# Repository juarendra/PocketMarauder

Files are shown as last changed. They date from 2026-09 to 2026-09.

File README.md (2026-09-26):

# PocketMarauder

Perangkat pentest saku: **ESP32-WROOM-32D + OLED 128x64 (SSD1306) + 4 tombol**, berjalan di firmware fork [ESP32Marauder](https://github.com/Spacehuhn/ESP32Marauder) dengan 4 fitur pentest tambahan yang di-build khusus untuk target `POCKET_MARAUDER`.

```
[ OLED 128x64 ]   [ ESP32-WROOM-32D ]
  I2C (IO21/22)     [ A ] [ B ] [ C ] [ D ]   (IO35/32/33/25)
                    Bat: LiPo via TP4056 (IO34)   LED aktif: IO19
```

> **Gambar hardware**: [`docs/images/hardware-placeholder.png`](docs/images/hardware-placeholder.png) — masih placeholder; foto/diagram asli menyusul.

## Fitur

### Firmware bawaan ESP32Marauder (v1.17.0)
- **WiFi** — sniffers (beacon/probe/deauth/EAPOL), scanners (channel analyzer, PineScan, Fox Hunt), attacks (deauth, beacon spam, Karma, Evil Portal, SAE commit, dst.), packet monitor.
- **Bluetooth** — sniffers (BLE scan, FindMy/Airtag, CC skimmer), attacks (Sour Apple, BLE spam, Spoof Airtag).
- **OLED natif** — menu + status bar + persentase baterai, tanpa TFT.
- **Baterai** — ADC IO34 (divider 5.02×), ditampilkan % di status bar.
- **LED aktivitas** — hijau di IO19, menyala saat scan/attack aktif.

### Fitur tambahan (khusus PocketMarauder)
| Fitur | Menu | Fungsi |
|---|---|---|
| **WPS Scan** | WiFi → Sniffers | Pasif: deteksi AP yang mengiklankan WPS, flag `PIN-PRONE` / `LOCKED` |
| **Probe Spam** | WiFi → Attacks | Flood probe request dengan SSID acak |
| **Roam Bait** | WiFi → Attacks | Beacon palsu dengan IE 802.11r (MD) + 802.11k (RM caps) |
| **GATT Explore** | BT → Attacks | Koneksi BLE, enumerasi services/characteristics/values |

Detail penggunaan per fitur: [`docs/USER_MANUAL.md`](docs/USER_MANUAL.md).

## Hardware

| Komponen | Detail |
|---|---|
| MCU | ESP32-WROOM-32D (2.4 GHz WiFi + BLE) |
| Tampilan | SSD1306 OLED 128x64 mono, I2C addr `0x3C` (SDA=IO21, SCL=IO22) |
| Tombol | A=Up (IO35), B=Left/Back (IO32), C=Center/Select (IO33), D=Down (IO25) — active-low, pull-up 10k |
| Baterai | LiPo via charger TP4056 + proteksi; tegangan dibaca IO34 (ADC1_CH6, divider 10k/40.2k) |
| LED | Hijau IO19 (active-low), indikasi aktivitas scan |
| Antena | U.FL — gunakan antena tersambung untuk hasil scan maksimal |

PCB/EAGLE source: [`PCB/EAGLE/`](PCB/EAGLE/).

## Build & Flash

Prasyarat: [PlatformIO](https://platformio.org) CLI + Python 3.

```bash
cd firmware
python -m platformio run -e pocket_marauder        # build (~60 detik)
python -m platformio run -e pocket_marauder -t upload   # flash (butuh USB flasher)
python -m platformio run -e pocket_marauder -t monitor  # serial monitor
```

Build terakhir: **GREEN** — Flash 81.7% (1605679/1966080), RAM 24.9% (81724/327680).

Output: `firmware.bin` (app) + `firmware.factory.bin` (gabungan bootloader + partisi + app).

## Struktur Repo

```
firmware/            firmware (fork ESP32Marauder, target POCKET_MARAUDER)
  esp32_marauder/    source utama
  tools/             build helpers PlatformIO
  installer/         build pipeline installer
PCB/EAGLE/           source PCB (schematic)
docs/
  USER_MANUAL.md     manual pengguna (lengkap)
  images/            simulasi tampilan OLED + placeholder hardware
  plans/             rencana kerja internal
CHANGELOG.md         log perubahan
```

## Lisensi

[GNU GPL v3](LICENSE). Fork dari ESP32Marauder (upstream juga GPLv3).

## Disclaimer

Alat ini untuk **pengujian keamanan yang sah** (lab sendiri, jaringan sendiri, atau dengan izin tertulis pemilik jaringan). Penggunaan di jaringan yang tidak kamu miliki tanpa izin adalah **ilegal** di hampir semua yurisdiksi. Pengguna bertanggung jawab penuh atas perbuatannya.

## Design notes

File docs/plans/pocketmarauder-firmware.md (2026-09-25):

# PocketMarauder — Review & Plan

Updated: 2026-09-25
Status: PLAN — belum eksekusi, nunggu approval

## 1. Review Hardware (dari EAGLE sch + BOM + gerber)

Board: **espmarauder v2 / "PocketMarauder"** — SlimeVR by Positron Elektronik.
Sumber: `PCB/EAGLE/espmarauder.sch` (EAGLE 9.6.2), BOM `CAMOutputs/Assembly/espmarauder.txt`,
gerber `espmarauder_production_2026-03-05.zip`.

### Fakta terverifikasi
- **MCU**: ESP32-WROOM-32D (single unit; board produksi = 2 unit identik di-panel, konfirmasi user).
- **USB-UART**: FT231XS-R (auto-program via DTR/RTS Q1/Q2).
- **Power**: TP4056 charger + DW01A/FS8205A Li-ion protection + M3406-ADJ buck 3.3V + SI2301 P-MOSFET load switch. JST-PH2 battery + slide switch BATT_SW.
- **Display**: **OLED 128x64 I2C SSD1306** (`DISPLAY-OLED-128X64-I2C`, U$1).
  - SDA = **IO21**, SCL = **IO22**.
- **Buttons** (4x tactile 4x4, active-low, pull-up eksternal 10k):
  | Fungsi fisik | Net | GPIO | Pull-up |
  |---|---|---|---|
  | BTN A | D35 | **IO35** | R6 10k |
  | BTN B | D32 | **IO32** | R11 10k |
  | BTN C | D33 | **IO33** | R18 10k |
  | BTN D | D25 | **IO25** | R19 10k |
  - Catatan: net `BUTTON1` ada di **IO18** tapi tanpa komponen tombol → sisa template, abaikan.
  - IO35 = input-only (OK, pakai pull-up eksternal, tak bisa internal).
- **LED user**: LED = **IO19** (R9 330), LED2 = **IO26** (R20 330). Plus CHRG/STBY/RX/TX status LED (hardware, bukan GPIO).
- **microSD**: **TIDAK ADA** konektor di BOM. Net `SD_HOST_*` (IO2/4/12/13/14/15) = sisa template → matikan (konfirmasi user).
- **UART2** IO16/IO17 (RX_DWM/TX_DWM): bekas project lain → abaikan (konfirmasi user).
- **Board**: 2-layer, 80.0 x 48.5 mm, tebal 1.57mm. Gerber siap fab (EAGLE CAM, 13 file + drill).

## 2. Review Firmware (upstream justcallmekoko/ESP32Marauder v1.17.0)

### BLOCKER kritis — display incompatible
Upstream Marauder **hanya support TFT warna via TFT_eSPI** (ILI9341/ST7735/ST7789/CYD dst).
**Tidak ada driver OLED SSD1306 / monochrome sama sekali** di seluruh codebase
(cek: 0 match `SSD1306|SH1106|U8g2|Adafruit_GFX`).

`Display` class terikat erat ke API TFT_eSPI:
- `tft.drawString/setFreeFont/setTextColor`, `TFT_eSPI_Button`, warna 16-bit RGB565.
- Layout menu diasumsikan min ~135x240 px berwarna. OLED cuma 128x64 mono.

→ **Remap GPIO saja TIDAK cukup.** Board ini butuh backend display baru.

### Yang cocok tanpa modif besar
- WiFi/BT attack core (WiFiScan, EvilPortal, CommandLine) hardware-agnostik.
- `HAS_SCREEN` bisa dimatikan → firmware jalan **headless** (kontrol via serial CLI 115200).
- Build target `GENERIC_ESP32` sudah ada (screen off, button off) sebagai basis.

## 3. Arsitektur Display (KEPUTUSAN: Opsi B)
| Opsi | Effort | Hasil | Risiko |
|---|---|---|---|
| **A. Headless/CLI** | Kecil | Semua fitur attack via serial; OLED tak dipakai / status ringkas manual | Tak ada menu di device — kurang "produk" |
| **B. OLED backend baru** | Besar | Menu native di OLED 128x64 + 4 tombol | Nulis ulang layer Display (drawString, button, scroll) untuk SSD1306; port paling berat |
| **C. Fork komunitas OLED** | Sedang | Pakai fork Marauder yg sudah OLED (mis. varian 0.96") lalu remap | Perlu cari fork yg maintained & sinkron fitur; lisensi/quality bervariasi |

### KEPUTUSAN USER (2026-09-25)
- **Opsi B dipilih** — OLED backend baru (SSD1306 128x64 + 4 tombol nav).
- **Branding**: nama produk = **PocketMarauder**.
- **Boot logo**: foto French Bulldog (`local://image-c9ef49c3d688ab6a.png`, 433x577 PNG).
  → konversi ke bitmap 1-bit 128x64 (XBM), threshold/dither, di Fase 2.
- **Fitur ekstra**: user minta saran (lihat §3b).

## 3b. Saran Fitur (di luar Marauder standar)

Konteks board: OLED 128x64 mono, 4 tombol, battery Li-ion + TP4056, tanpa SD/GPS.
Semua yg butuh SD/GPS di upstream otomatis di-disable.

Prioritas layak (murah, cocok hardware ini):
1. **Battery indicator di status bar** — baca VBAT via ADC divider bila ada net battery-sense; kalau tak ada tap ADC, tampilkan status charging dari pin TP4056 CHRG/STBY (bila terhubung GPIO). Cek dulu di sch apakah ada.
2. **Nav 4-tombol yang enak** — mapping Up/Down/Select/Back (bukan 5-arah), karena cuma 4 tombol. Long-press = Back global.
3. **Boot logo + versi + nama** — splash PocketMarauder 2 detik.
4. **Sleep/backlight-off timeout** — OLED aging + hemat baterai; wake on button.

Opsional (nice-to-have):
5. Menu "Favorites" — shortcut ke 2-3 scan yg paling sering (deauth detector, beacon spam, packet monitor) biar cepat di layar kecil.
6. Indikator RAM/heap ringkas di status bar (Marauder rentan OOM).

Dihindari (tak cocok / tak ada hardware):
- Wardriving/GPS log (tak ada GPS + tak ada SD buat simpan).
- PCAP ke SD (tak ada SD) — hanya live serial dump.
### Fase 1 — Board config
- [ ] Tambah target `POCKET_MARAUDER` di `firmware/esp32_marauder/configs.h`:
  - Buttons: L/C/U/D/R → IO35/IO32/IO33/IO25 (+ mapping ke navigasi menu).
  - `HAS_BUTTONS`, `HAS_BT`, matikan `HAS_SD`/`HAS_GPS`.
  - I2C: SDA=21, SCL=22.
- [ ] Boot splash + `HARDWARE_NAME "PocketMarauder"` (branding).
- Bukti: compile config-only, cek makro resolve.

### Fase 2 — Display (sesuai opsi terpilih A/B/C)
- A: `HAS_SCREEN` off, verifikasi CLI. Bukti: serial log scan WiFi.
- B: implement `DisplayOLED` (SSD1306 via Adafruit_SSD1306/U8g2), adaptor menu. Bukti: foto OLED render menu.

### Fase 3 — Build & flash
- [ ] Build via arduino-cli (toolchain terdeteksi: `arduino-cli` ada; PlatformIO belum).
- [ ] Flash 1 unit, smoke test: boot → menu/CLI → 1 scan WiFi sukses.
- [ ] Dokumentasi prosedur flash produksi (2 unit per panel).

### Fase 4 — Cleanup
- [ ] Hapus `_tmp_marauder`, file bekas, update CHANGELOG.

## 5. Toolchain terdeteksi
- `arduino-cli` ✓ (`C:\Program Files\Arduino CLI`)
- `git`, `python3` ✓
- PlatformIO ✗ (upstream punya `platformio.ini` tapi cuma buat env `native` test; build device pakai Arduino IDE/CLI).

## 6. Keputusan yang ditunggu dari user
1. **Opsi display A / B / C?** (paling menentukan scope).
2. Branding: nama produk final, boot logo custom? (punya aset sendiri?).
3. Fitur firmware di luar Marauder standar yang mau ditambah? (blm ada, konfirmasi).

## Don't repeat
- Upstream TIDAK punya OLED driver — jangan asumsikan remap GPIO cukup untuk display.
- Board TANPA microSD & GPS meski net template ada.

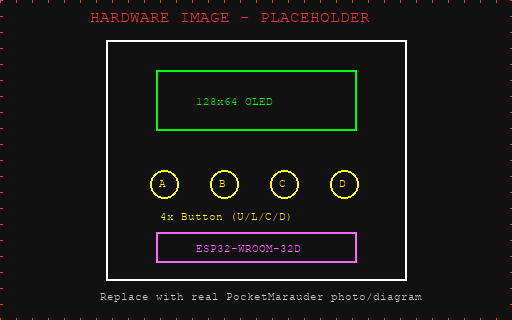
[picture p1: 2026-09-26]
docs/images/hardware-placeholder.png

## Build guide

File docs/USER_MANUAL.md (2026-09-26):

# PocketMarauder — Manual Pengguna

Manual ini menjelaskan cara menggunakan perangkat PocketMarauder dari awal: menyalakan, menavigasi menu, memakai semua fitur, sampai membaca output di serial monitor. Gambar-gambar di bawah adalah **simulasi tampilan OLED** (piksel asli perangkat adalah 128x64 mono; simulasi di-skalakan 4× agar terbaca).

---

## 1. Sekilas Perangkat

PocketMarauder adalah perangkat pentest saku berbasis ESP32 dengan:

- **OLED 128x64** monokrom — semua tampilan menu & hasil di sini.
- **4 tombol fisik** — navigasi & eksekusi.
- **WiFi 2.4 GHz** (ch 1-14) + **Bluetooth LE** (BLE 4.2/5.0).
- **Baterai LiPo** terintegrasi + **LED hijau** indikator aktivitas.

> **Gambar hardware**: [`images/hardware-placeholder.png`](images/hardware-placeholder.png)
> (masih placeholder — foto/diagram perangkat asli menyusul di folder yang sama; manual ini akan menunjuk ke file `hardware.png` begitu tersedia.)

## 2. Tombol & Navigasi

Semua tombol active-low, dengan pull-up.

| Tombol | Posisi GPIO | Fungsi |
|---|---|---|
| **A** (atas) | IO35 | Naik satu item menu |
| **B** (kiri) | IO32 | **Back** — kembali ke menu sebelumnya; menghentikan scan/attack yang berjalan |
| **C** (tengah) | IO33 | **Select/Enter** — membuka item yang disorot / memulai scan |
| **D** (bawah) | IO25 | Turun satu item menu |

Aturan navigasi:

1. Item yang disorot di-highlight (baris putih terbalik, awalan `>`).
2. Menu ber-scroll jika item melebihi satu layar.
3. Tekan **B** kapan pun untuk berhenti & kembali.
4. Setelah scan/attack selesai (ditutup tombol B), perangkat kembali ke menu utama.

## 3. Daya, Baterai, LED

### Menyalakan / Mematikan
Perangkat menyala saat diberi daya (baterai terpasang + saklar on, atau via USB charger TP4056). Tidak ada tombol power terpisah — matikan dengan memutus daya/saklar.

### Membaca Persentase Baterai
Status bar di baris paling atas OLED selalu menampilkan persentase baterai di sisi kanan (contoh: `84%`):

```
PocketMarauder                    84%
──────────────────────────────────
```

- Persentase dihitung dari tegangan baterai via divider (IO34), di-refresh tiap 3 detik.
- **Hijau** (dalam serial log) / tampilan normal: > 20%. Di bawah 20% persentase akan terlihat merah di log serial dan sebaiknya segera diisi ulang.
- Mengisi ulang: colokkan ke pengisi LiPo (port TP4056) — perangkat boleh tetap menyala.

### LED Hijau (IO19)
- **Menyala** = perangkat sedang melakukan WiFi scan/attack.
- **Padam** = idle di menu.
LED berguna untuk tahu secara sekilas (tanpa melihat layar) apakah ada operasi berjalan.

## 4. Urutan Boot

1. **Splash** — logo + "PocketMarauder" + versi, ~1 detik.
2. Inisialisasi OLED, WiFi radio, BLE.
3. Menu utama muncul; status bar mulai menampilkan persentase baterai.

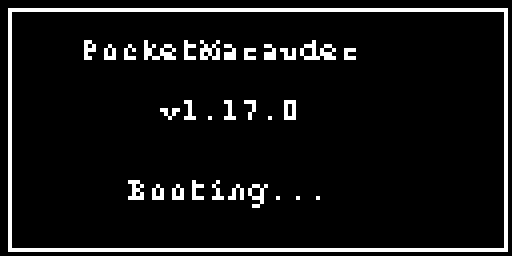
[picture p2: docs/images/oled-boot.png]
Boot


## 5. Struktur Menu

```
Main Menu
├── Recon            → (aplikasi umum)
├── WiFi
│   ├── Sniffers     → Probe / Beacon / Deauth / EAPOL / Packet Monitor /
│   │                  Channel Analyzer / SA Commit / ★ WPS Scan
│   ├── Scanners     → Channel Analyzer & Summary, Fox Hunt, MAC Monitor
│   ├── Attacks      → Beacon List / Beacon Spam / Evil Portal / Deauth /
│   │                  ★ Probe Spam / ★ Roam Bait / Karma / Bad Msg / dst.
│   └── General Apps → Evil Portal, dll.
├── Bluetooth
│   ├── Sniffers     → Bluetooth Sniff, FindMy, CC Skimmers, Fox Hunt
│   └── Attacks      → Sour Apple, Apple Juice, Swiftpair Spam, BLE Spam,
│                      Spoof Airtag, ★ GATT Explore
├── Device           → info perangkat (versi, MAC, memory, baterai)
└── Reboot           → restart perangkat
```

`★` = fitur tambahan khusus PocketMarauder.

### 5.1 Main Menu

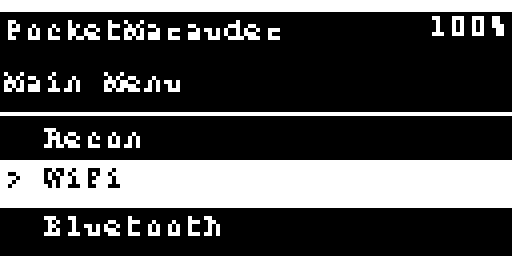
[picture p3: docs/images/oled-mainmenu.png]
Main Menu


Sorot `WiFi` (tombol A/D), tekan **C**.

### 5.2 Menu WiFi

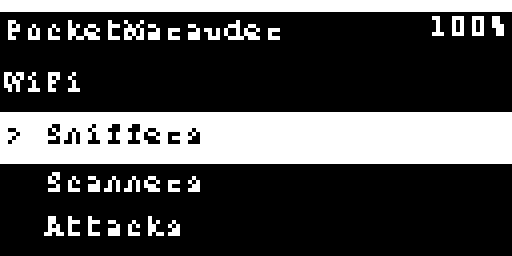
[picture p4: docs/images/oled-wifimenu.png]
Menu WiFi


### 5.3 Submenu WiFi → Sniffers

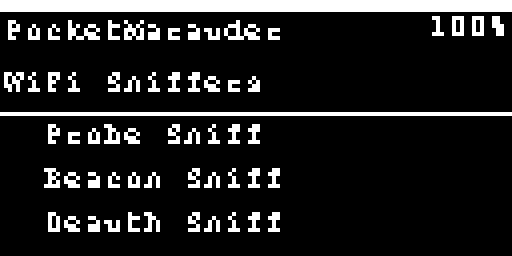
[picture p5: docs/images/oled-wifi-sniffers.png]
WiFi Sniffers


### 5.4 Submenu WiFi → Attacks

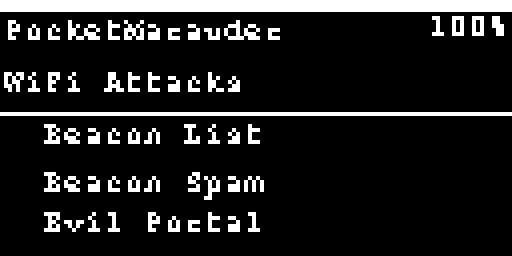
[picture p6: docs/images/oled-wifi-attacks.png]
WiFi Attacks


### 5.5 Submenu BT → Attacks

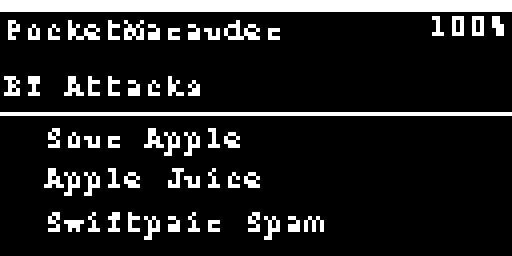
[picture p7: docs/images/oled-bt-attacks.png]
BT Attacks


## 6. Fitur Bawaan (ringkasan)

Fitur-fitur berikut berasal dari firmware ESP32Marauder upstream dan bekerja standar. Berikut ringkasan singkat; untuk detail penuh, konsultasikan dokumentasi upstream.

### 6.1 WiFi Sniffers
| Item | Yang dilakukan |
|---|---|
| **Probe Sniff** | Menangkap probe request dari client WiFi (SSID yang dicari client) |
| **Beacon Sniff** | Menangkap beacon frame — daftar AP di sekitar (SSID, MAC, channel, RSSI, encryption) |
| **Deauth Sniff** | Menangkap deauthentication frame |
| **EAPOL** | Menangkap frame autentikasi WPA handshake |
| **Packet Monitor** | Visualisasi throughput/frame rate secara real-time |
| **Channel Analyzer** | Grafik okupansi per channel |
| **SAE Commit** | Menangkap WPA3 SAE commit |

Hasil muncul di layar (baris-baris AP) dan di serial monitor (lebih lengkap).

### 6.2 WiFi Scanners & Attacks (bawaan)
- **Channel Summary / Analyzer** — okupansi channel 1-14.
- **Fox Hunt** — lacu AP/STA spesifik.
- **MAC Monitor** — deteksi perangkat yang "mengikuti" (mac monitor).
- **Beacon List / Beacon Spam** — broadcast beacon SSID dari list.
- **Evil Portal** — captive portal + portal phishing framework.
- **Deauth** — kirim deauth (broadcast atau targeted).
- **Karma** — probe-based SSID replay.
- **Bad Msg / Assoc Sleep / SAE Commit Flood / Channel Switch / Quiet Time** — varian attack lain.

### 6.3 Bluetooth
- **Bluetooth Sniff** — scan BLE umum (nama, MAC, RSSI) → juga mengisi daftar device yang dipakai fitur GATT Explore (lihat §7.3).
- **FindMy Sniff/Monitor** — deteksi AirTag & tracker FindMy.
- **CC Skimmers** — deteksi skimmer kartu kredit berbasis BLE (NFC/CC).
- **Sour Apple / Apple Juice** — Apple BLE spam.
- **Swiftpair Spam / Samsung / Google / Flipper BLE Spam / BLE Spam All** — flood BLE advertisement.
- **Spoof Airtag** — simulasi AirTag.

## 7. Fitur Tambahan PocketMarauder (Detail)

Keempat fitur di bawah adalah penambahaan di firmware ini. Output detail keempatnya **terutama tampil di serial monitor** — layar OLED menampilkan status berjalan; hasil lengkap (SSID/MAC/UUID/nilai) dibaca dari serial (lihat §9).

### 7.1 WPS Scan (pasif)

**Lokasi menu:** `WiFi → Sniffers → WPS Scan`

**Apa yang dilakukan:** Mode *pasif* — tidak mengirim satu pun frame. Perangkat menangkap beacon + probe-response dari AP di sekitar, lalu memeriksa IE (Information Element) WPS di tiap frame:

1. Cari vendor IE WPS (OUI `00:50:F2`, type `0x04`).
2. Di dalamnya baca **Config Methods** (atribut `0x1008`) dan **AP Setup Locked** (atribut `0x1057`).

**Klasifikasi hasil per AP:**
| Flag | Arti |
|---|---|
| **PIN-PRONE** | WPS aktif dan method **PIN/keypad** diiklankan → AP rentan terhadap WPS PIN brute-force (offline attack dengan captured EAPOL) |
| **LOCKED** | AP Setup Locked = 1 → PIN WPS dikunci (gagal berulang) — tidak bisa di-PIN lagi sampai direset |
| **WPS** | AP mengiklankan WPS dengan method lain (display/PBC) — dicatat, bukan target PIN |

AP yang tidak punya IE WPS sama sekali tidak ditampilkan.

**Cara pakai:**
1. `WiFi → Sniffers → WPS Scan`, tekan **C**.
2. Perangkat men-scan promiscuous di semua channel (hop channel otomatis).
3. AP yang terdeteksi tampil di layar & serial, sekali per MAC (deduplikasi).
4. Tekan **B** untuk berhenti.

**Contoh output serial:**
```
WPS: AP AC:1F:88:A1:B2  SSID TP-Link_5G  CH 6
     WPS PIN-PRONE  (methods: keypad 0x8)  locked: NO
WPS: AP 8C:AA:C2:99:D4  SSID HomeNet  CH 11
     WPS LOCKED  (methods: display 0x10)  locked: YES
```

**Catatan penting:** Ini *hanya pengamatan pasif* (setara memindai jaringan). Tidak ada injeksi WPS PIN — ESP32 tidak memiliki supplicant WPS untuk attack aktif. Untuk eksploitasi aktif pada AP yang `PIN-PRONE`, diperlukan tools di PC (mis. hcxdumptool/hcxpcapng + eapol2wps + airpwn) yang bekerja pada capture hasil scan ini.

**Simulasi layar saat berjalan:**
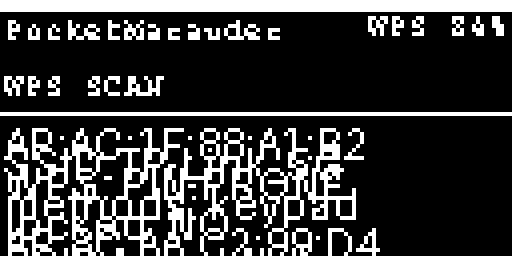
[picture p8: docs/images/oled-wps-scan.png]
WPS Scan


### 7.2 Probe Spam

**Lokasi menu:** `WiFi → Attacks → Probe Spam`

**Apa yang dilakukan:** Membangun & memflood **probe request** dengan SSID acak (panjang 1-32 karakter, dari alphabet a-z 0-9) dan source MAC acak, di setiap channel. Tiap tick (~interval main loop) dikirim **55 frame** per channel, lalu hop channel.

**Kegunaan (pentest):**
- Mengukur bagaimana AP/controller enterprise merespon volume probe request yang tidak wajar (rate-limiting, alarm IDS, perilaku fail-safe).
- Mengisi log client dengan probe SSID tidak dikenal untuk melatih deteksi anomaly.
- Uji ketahanan monitoring wireless (WIDS/WIPS).

**Cara pakai:**
1. `WiFi → Attacks → Probe Spam`, tekan **C**.
2. Layar menampilkan counter packet & channel saat ini; LED hijau menyala.
3. Tekan **B** untuk berhenti.

**Simulasi layar saat berjalan:**
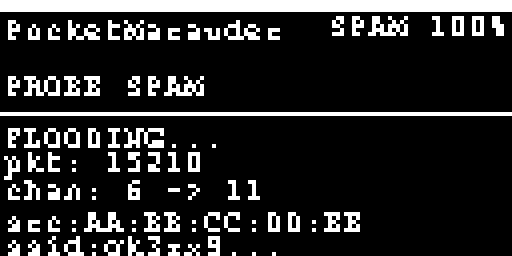
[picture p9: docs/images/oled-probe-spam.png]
Probe Spam


### 7.3 GATT Explore (BLE)

**Lokasi menu:** `BT → Attacks → GATT Explore`

**Prasyarat:** Harus ada **daftar device BLE** dulu. Jalankan `BT → Sniffers → Bluetooth Sniff` (atau scan BLE lain) sampai ada device, baru masuk ke GATT Explore.

**Apa yang dilakukan:**
1. Menampilkan submenu berisi device BLE yang ter-scan (nama + RSSI).
2. Pilih satu device → perangkat **connect** sebagai BLE client (NimBLE).
3. **Enumerasi GATT**: daftar semua Service → setiap Characteristic dengan propertinya:
   - `[R]` = readable, `[W]` = writable, `[N]` = notify, `[I]` = indicate
   - Jika readable: **nilai saat ini di-read** dan dicetak (hex + string jika printable).
4. Setelah selesai, device diputuskan sambungannya otomatis.

**Kegunaan (pentest):** Memetakan permukaan attack GATT sebuah device BLE (mana yang bisa dibaca/ditulis/notified) — langkah awal untuk analisis security device IoT/BLE.

**Contoh output serial:**
```
GATT: connecting to AA:BB:CC:DD:EE:FF
GATT: connected
  Service 0x180F (Battery Service)
    Char 0x2A19 (Battery Level) [R] = 87
  Service 0x180A (Device Information)
    Char 0x2A24 (Manufacturer Name) [R] = PocketMarauder
    Char 0x2A25 (Model Number) [R] = PM-01
GATT: enumeration complete. Disconnecting.
```

**Catatan:** Device yang tidak mengizinkan connect (bonding hanya, atau whitelist) akan gagal — lihat pesan error di serial. Beberapa device memutus koneksi saat dibaca agresif.

**Simulasi layar saat berjalan:**
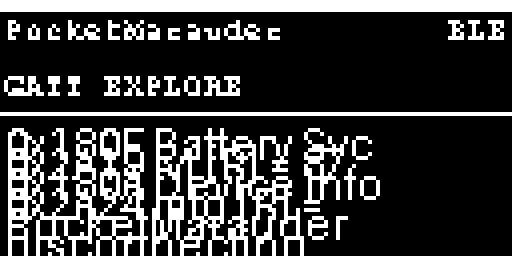
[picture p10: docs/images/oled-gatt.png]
GATT Explore


### 7.4 Roam Bait (Beacon 802.11r/11k)

**Lokasi menu:** `WiFi → Attacks → Roam Bait`

**Apa yang dilakukan:** Membroadcast beacon frame dengan SSID acak yang membawa dua Information Element khusus:

| IE | Tag | Isi | Fungsi |
|---|---|---|---|
| **802.11r** — Mobility Domain | `0x36` | MD Identifier `0x0ABC` + Individual C | Menandai beacon sebagai bagian dari "fast roam domain" (FT) |
| **802.11k** — RM Enabled Capabilities | `0x46` | `0x73` (bit: enabled + external APs report + beacon report) | Mengklaim dukungan Radio Measurement |

**Kegunaan (pentest):** Menguji apakah client enterprise (laptop/phone yang dikonfigurasi Fast Roam) **tertarik & mencoba pindah** ke AP palsu ini, atau apakah WIDS mendeteksi beacon 11r/11k yang tidak terdaftar di kontroler. Berguna untuk memvalidasi konfigurasi roaming security (FT SAIC validation, PMK caching).

**Cara pakai:**
1. `WiFi → Attacks → Roam Bait`, tekan **C**.
2. Beacon dikirim per tick di channel saat itu (channel mengikuti hop).
3. Tekan **B** untuk berhenti.

**Simulasi layar saat berjalan:**
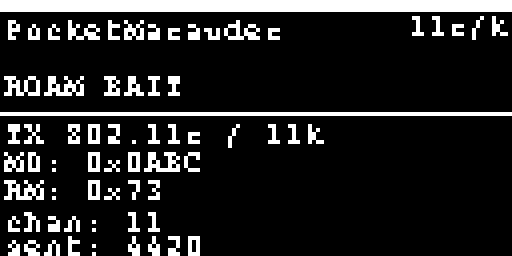
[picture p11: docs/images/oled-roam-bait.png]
Roam Bait


## 8. Status Bar

Baris teratas OLED di semua menu:

```
+------------------------------------------+
| PocketMarauder            [icons]  84%   |
+------------------------------------------+
```

- **Kiri** — nama perangkat / nama menu aktif.
- **Kanan** — persentase baterai (refresh 3 detik).
- Di beberapa mode ada counter (pkt/kanal) menggantikan ikon.

## 9. Membaca Output di Serial Monitor

Layar 128x64 terbatas; **detail hasil (terutama 4 fitur tambahan) keluar lewat serial USB (115200 baud)**.

1. Sambungkan perangkat ke PC via kabel USB (port serial).
2. Buka serial monitor (PlatformIO: `python -m platformio run -e pocket_marauder -t monitor`, atau PuTTY/Arduino IDE/`screen` di baud 115200).
3. Jalankan fitur apa pun — output detail (MAC, SSID, UUID, hex value) tercetak real-time.

> **Catatan:** bila port serial dipakai untuk **flash**, monitor tidak bisa buka bersamaan. Pasang dulu, buka monitor, baru gunakan.

## 10. Tips & Troubleshooting

| Gejala | Penyebab / Solusi |
|---|---|
| OLED hitam total | Cek I2C (SDA=21, SCL=22); coba reboot; address default 0x3C |
| Persentase baterai loncat-loncat | Normal — dibaca ADC tiap 3 detik; cek koneksi battery |
| LED tidak menyala saat scan | LED active-low; pastikan tidak ada short di IO19 |
| GATT Explore tidak muncul / kosong | Belum ada device BLE — jalankan dulu BT Sniff |
| GATT connect gagal | Device tidak mengizinkan client, atau di luar jangkauan |
| WPS Scan tidak menemukan AP | Memang tidak ada AP WPS di sekitar (sebagian besar AP modern sudah mematikan WPS) |
| Scan WiFi tidak banyak hasil | Pastikan antena U.FL tersambung & perangkat di area terbuka |
| Build gagal di `pio run` | Pastikan `python -m platformio` versi terbaru & sudah `pio` platform terunduh |

## 11. FAQ

**Q: Apakah perangkat bisa dipakai offline (tanpa PC)?**
A: Ya. Semua fitur berjalan standalone; hasil tampil di OLED + tersimpan di memori. Output detail & capture PC butuh kabel serial.

**Q: Baterai tahan berapa lama?**
A: Tergantung mode. Scan WiFi kontinu ≈ 2-3 jam; idle ≈ 12+ jam. Monitor persentase di status bar.

**Q: Apakah ada SD card untuk simpan capture?**
A: Tidak di board ini (desain tanpa slot SD). Capture tersimpan di RAM/flash sementara & serial.

**Q: Bagaimana cara update firmware?**
A: Flash ulang `firmware.bin` terbaru (build §README) via PlatformIO.

## 12. Disclaimer Hukum

Perangkat ini disediakan **untuk pengujian keamanan yang sah**: laboratorium milik sendiri, jaringan yang kamu miliki, atau dengan **izin tertulis eksplisit** dari pemilik jaringan.

Mengoperasikan attack (deauth, spam, beacon palsu, dsb.) terhadap jaringan yang tidak kamu miliki **tanpa izin** adalah pelanggaran hukum (mis. UU ITE di Indonesia, CFAA di AS, Computer Misuse Act di UK). Pengguna sepenuhnya bertanggung jawab atas penggunaan perangkat ini.

---
*Versi manual: 1.0 — selaras dengan firmware v1.17.0 + fitur tambahan PocketMarauder (commit `c1cb904`).*

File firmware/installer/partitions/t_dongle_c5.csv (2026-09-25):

# LilyGo T-Dongle C5 16 MB layout
# Name | Type | SubType | Offset | Size | Flags
nvs | data | nvs | 0x9000 | 0x5000
otadata | data | ota | 0xe000 | 0x2000
app0 | app | ota_0 | 0x10000 | 0x300000
app1 | app | ota_1 | 0x310000 | 0x300000
spiffs | data | spiffs | 0x610000 | 0x9F0000

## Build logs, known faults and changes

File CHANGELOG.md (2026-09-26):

# Changelog

All notable changes to PocketMarauder firmware. Format loosely follows
Conventional Commits; each entry: context, change (paths), evidence, impact, rollback.

## Unreleased

### docs: add user manual, README, LICENSE, OLED sim images, hardware placeholder
- Context: user requested a complete detailed end-user manual, a project README, a chosen license, simulated OLED display images, and a hardware image placeholder (real hardware photo to be supplied later by user).
- Change:
  - NEW `LICENSE`: full GNU GPL v3 text + PocketMarauder copyright header. Chose GPL-3.0 because this repo is a fork of ESP32Marauder (upstream is GPL-3.0); a permissive license would violate upstream copyleft.
  - REWROTE `README.md`: hardware overview (placeholder image), feature table (stock + 4 PocketMarauder additions), build/flash, repo structure, license + legal disclaimer.
  - NEW `docs/USER_MANUAL.md`: 12-section end-user manual (Indonesian) — buttons/navigation, power/battery/LED, boot, full menu tree, stock features summary, the 4 added features in depth (what they do, how to run, expected serial output, notes), status bar, serial-monitor usage, troubleshooting table, FAQ, legal disclaimer.
  - NEW `docs/images/`: 10 simulated 128x64 monochrome OLED screens (boot, main menu, WiFi menu, WiFi sniffer, WiFi attacks, BT attacks, WPS scan, probe spam, GATT explore, roam bait) rendered at 4x scale + 1 `hardware-placeholder.png` for the device (to be replaced with a real photo/diagram).
- Evidence: `docs/images/` contains 11 PNGs; all 11 `images/*.png` references in USER_MANUAL.md resolve to existing files (verified via grep).
- Impact: end users get a self-contained manual + visual reference; project is now licensed (GPL-3.0) and documented. No firmware code changed.
- Rollback: delete `LICENSE`, `docs/USER_MANUAL.md`, `docs/images/`, and revert `README.md`.

### feat: add 4 pentest features (WPS scan, probe spam, GATT explore, roam bait) for POCKET_MARAUDER
- Context: user requested 4 additive pentest tools wired into the menu + scan dispatch. All legal-equivalent (no RF jammer). WPS downgraded to a passive scanner (ESP32 has no WPS supplicant injection).
- Change (all `POCKET_MARAUDER`-neutral; new scan-mode ids 87-90):
  - `firmware/esp32_marauder/WiFiScan.h`: added `WIFI_SCAN_WPS 87`, `WIFI_ATTACK_PROBE_SPAM 88`, `WIFI_ATTACK_ROAM_BAIT 89`, `BT_GATT_EXPLORE 90`; method decls `sendProbeFlood`, `broadcastRoamBait`, `beaconWPSInfo`, `runGattExplore`(NimBLE2), `RunWPSScan`, `RunGattExplore`, `setGattTarget` (public); members `gatt_target[6]`, `gatt_target_set`.
  - `firmware/esp32_marauder/WiFiScan.cpp`:
    - Feature 1 WPS: `beaconWPSInfo()` walks IEs for WPS vendor IE (OUI 00:50:F2 type 0x04), extracts Config Methods `0x1008` + AP-Setup-Locked `0x1057`; `apSnifferCallbackFull` WPS branch flags PIN-PRONE/LOCKED per beacon/probe-resp and prints to serial + OLED; `RunWPSScan()` promiscuous setup; channel-hop branch in `main()`.
    - Feature 2 probe spam: `sendProbeFlood()` floods probe requests with random SSIDs (1-32 chars via `alfa[random(65)]`) + random src MAC; `main()` loops 55x/tick + channel hop.
    - Feature 3 GATT explore: `runGattExplore(NimBLEAddress&)` connects (NimBLE 2.x client), enumerates services/characteristics (R/W/N/I props + read values), prints to serial; `RunGattExplore()` entry pulls target set via `setGattTarget()`; guarded `#ifdef HAS_BT`/`HAS_NIMBLE_2`.
    - Feature 4 roam bait: `broadcastRoamBait()` beacons with 802.11r Mobility Domain IE (tag `0x36`) + 802.11k RM Enabled Caps IE (tag `0x46`, neighbor-report bit); `main()` per-tick TX.
    - Wired all 4 into `StartScan()`, `StopScan()` OR-chains (WiFi + BT), `main()`.
  - `firmware/esp32_marauder/MenuFunctions.cpp`: menu nodes — "WPS Scan" in `wifiSnifferMenu`; "Probe Spam" + "Roam Bait" in `wifiAttackMenu`; "GATT Explore" device submenu (populated from `ble_devices`) in `bluetoothAttackMenu` under `#ifdef HAS_NIMBLE_2`.
- Evidence: `python -m platformio run -e pocket_marauder` -> `SUCCESS`, RAM 24.9% (81724/327680), Flash 81.7% (1605679/1966080). On-device verification PENDING (no ESP32 hardware attached; `pio device list` shows only BT serial COM ports).
- Impact: 4 new menu-launchable pentest modes; no stock target or `[env:native]` touched.
- Rollback: revert the WiFiScan.h/.cpp + MenuFunctions.cpp hunks; remove the 4 `#define`s (87-90).

### feat: enable battery ADC sensing + activity LED for POCKET_MARAUDER
- Context: board has a LiPo path (TP4056/DW01A/FS8205A) with a voltage divider on IO34 (net `D34`) and a green GPIO LED on IO19 (net `LED`, active-low). Firmware had battery/LED disabled for this target; user wants a battery state indicator + percentage on the OLED and the LED driven by firmware.
- Change:
  - `firmware/esp32_marauder/configs.h`: POCKET_MARAUDER feature block (~148-152) — added `HAS_BATTERY`, `BATTERY_ADC_PIN 34`, `BATTERY_ADC_MULTIPLIER_X100 502`, `HAS_ACT_LED`, removed stale "no battery" comment; ACT LED STUFF block (~3318) — `ACT_LED_PIN 19` + `ACT_LED_ACTIVE_LOW` and `ACT_LED_ON`/`ACT_LED_OFF` polarity macros (stock boards keep active-high).
  - `firmware/esp32_marauder/BatteryInterface.cpp`: ADC path sets `i2c_supported = true` so `MenuFunctions::battery()` renders the percentage on mini/OLED screens (previously gated on i2c fuel gauge only); replaced hardcoded `* 2` divider scale with `BATTERY_ADC_MULTIPLIER_X100 / 100` (5.02x for R3=10k / R4=40.2k, matches this board; stock boards unaffected when they define their own pin).
  - `firmware/esp32_marauder/esp32_marauder.ino` + `WiFiScan.cpp`: the 4 `digitalWrite(ACT_LED_PIN, LOW/HIGH)` sites now use `ACT_LED_ON`/`ACT_LED_OFF` so the active-low LED lights while scanning (was inverted on this board).
- Evidence: `python -m platformio run -e pocket_marauder` -> `SUCCESS`, RAM 24.9% (81716/327680), Flash 81.4% (1599767/1966080). Divider verified from schematic `PCB/EAGLE/espmarauder.sch`: R3=10k to GND, R4=40.2k to switched cell rail (net labelled `+5V`, electrically the battery V+ after BATT_SW feeding boost IC2 VIN), tap to IO34.
- Impact: OLED status bar shows battery % (green >20%, red otherwise) polled every 3s; activity LED on IO19 lights during WiFi scan/attack, off otherwise.
- Rollback: remove the 5 lines from the POCKET_MARAUDER feature block, the `ACT_LED_PIN 19`/polarity block from ACT LED STUFF, revert the two `BatteryInterface.cpp` lines and the 4 `digitalWrite` sites back to `LOW`/`HIGH`.

### feat: add PlatformIO build env for POCKET_MARAUDER
- Context: board needs Arduino-ESP32 3.x / IDF 5.x (configs.h defines `HAS_IDF_3`, `HAS_NIMBLE_2`); stock PlatformIO `espressif32` is frozen on core 2.x. Provide a reproducible device build alongside the existing `[env:native]` Unity host tests.
- Change:
  - `firmware/platformio.ini`: NEW additive `[env:pocket_marauder]` on the pioarduino platform fork (`platform-espressif32` release `55.03.312-1`, Arduino 3.3.12 / IDF 5.5.5), `board = esp32dev`, `framework = arduino`, `board_build.partitions = min_spiffs.csv`, `lib_extra_dirs` for vendored libs, `build_src_filter` excluding `libraries/` from the src builder, `build_flags` `-Wno-error=return-type -fcommon -Wl,--allow-multiple-definition` (upstream relies on pre-GCC10 defaults + ODR clashes), `extra_scripts = pre:tools/pio_framework_libs.py`. `[env:native]` untouched.
  - NEW `firmware/tools/pio_framework_libs.py`: adds every bundled framework library `src` dir to the global include path (arduino-esp32 3.x libs cross-include with no `depends=`), and force-builds+links the `Network` library that LDF misses (WiFi reaches it only via a quoted include).
  - `firmware/esp32_marauder/configs.h`: added `SCREEN_BUFFER`/`MAX_SCREEN_BUFFER 6` and a `POCKET_MARAUDER` MENU DEFINITIONS block (`BANNER_TIME`, `COMMAND_PREFIX`, `KEY_*`, `BUTTON_PADDING`) the build required.
  - `firmware/esp32_marauder/OledAdapter.h`: `setTextWrap()`, `getTextBounds` `uint16_t w,h` signature fixes for the 3.x Adafruit_GFX.
- Evidence: `python -m platformio run -e pocket_marauder` -> `SUCCESS`, RAM 24.9% (81620/327680), Flash 80.9% (1590663/1966080), `firmware.bin` + combined `firmware.factory.bin` created.
- Impact: reproducible device firmware build; host-test env unaffected.
- Rollback: delete `[env:pocket_marauder]` and `firmware/tools/pio_framework_libs.py`; revert the configs.h/OledAdapter.h hunks.

### feat: native SSD1306 OLED display backend
- Context: upstream firmware only supports TFT_eSPI color displays; PocketMarauder has a 128x64 mono SSD1306 I2C OLED. Needed a shim exposing the full TFT_eSPI method surface over Adafruit_SSD1306.
- Change:
  - NEW `firmware/esp32_marauder/OledAdapter.h`: `OledDisplay` (wraps `Adafruit_SSD1306`) + `OledButton` (mirrors `TFT_eSPI_Button`). Maps RGB565 -> 1-bit (0x0000 off, else on). Defines TFT_* color/pin/`KEY_*` macros normally from TFT_eSPI. Auto-flushes framebuffer per draw call (ponytail: per-call flush; upgrade to dirty-flag + one `display()` per frame).
  - `Display.h`/`Display.cpp`: compile-select OLED members/methods under `#ifdef POCKET_MARAUDER`; stock TFT path unchanged in `#else`.
  - `drawBootSplash()`: PocketMarauder path draws `pocket_logo.h` (Frenchie) then a "PocketMarauder" + version text card.
  - vendored libs `Adafruit_SSD1306`, `Adafruit_GFX`, `Adafruit_BusIO` into `firmware/esp32_marauder/libraries/`.
- Evidence: pending arduino-cli compile (next step).
- Impact: firmware renders native menu + splash on the OLED without touching other targets.
- Rollback: comment out `#define POCKET_MARAUDER`; adapter is inert without it.

### feat: add POCKET_MARAUDER board target
- Context: custom board (ESP32-WROOM-32D, SSD1306 128x64 I2C OLED, 4 buttons) needs its own target in the vendored ESP32Marauder firmware.
- Change: `firmware/esp32_marauder/configs.h`
  - board flag `POCKET_MARAUDER` (active) in BOARD TARGETS
  - `HARDWARE_NAME "PocketMarauder"`
  - feature block: `HAS_BT`, `HAS_BUTTONS`, `HAS_SCREEN`, `HAS_MINI_SCREEN` (no SD/GPS/battery/temp)
  - button block: L=IO32, C=IO33, U=IO35, D=IO25, R=-1; all `_PULL true` (external 10k)
  - display block: OLED_SDA=21, OLED_SCL=22, OLED_ADDR=0x3C, 128x64, `MENU_FONT NULL`
- Evidence: pinmap verified from `PCB/EAGLE/espmarauder.sch` net analysis.
- Impact: selects the custom board at compile time; other targets untouched (commented).
- Rollback: comment out `#define POCKET_MARAUDER` at configs.h line ~48.

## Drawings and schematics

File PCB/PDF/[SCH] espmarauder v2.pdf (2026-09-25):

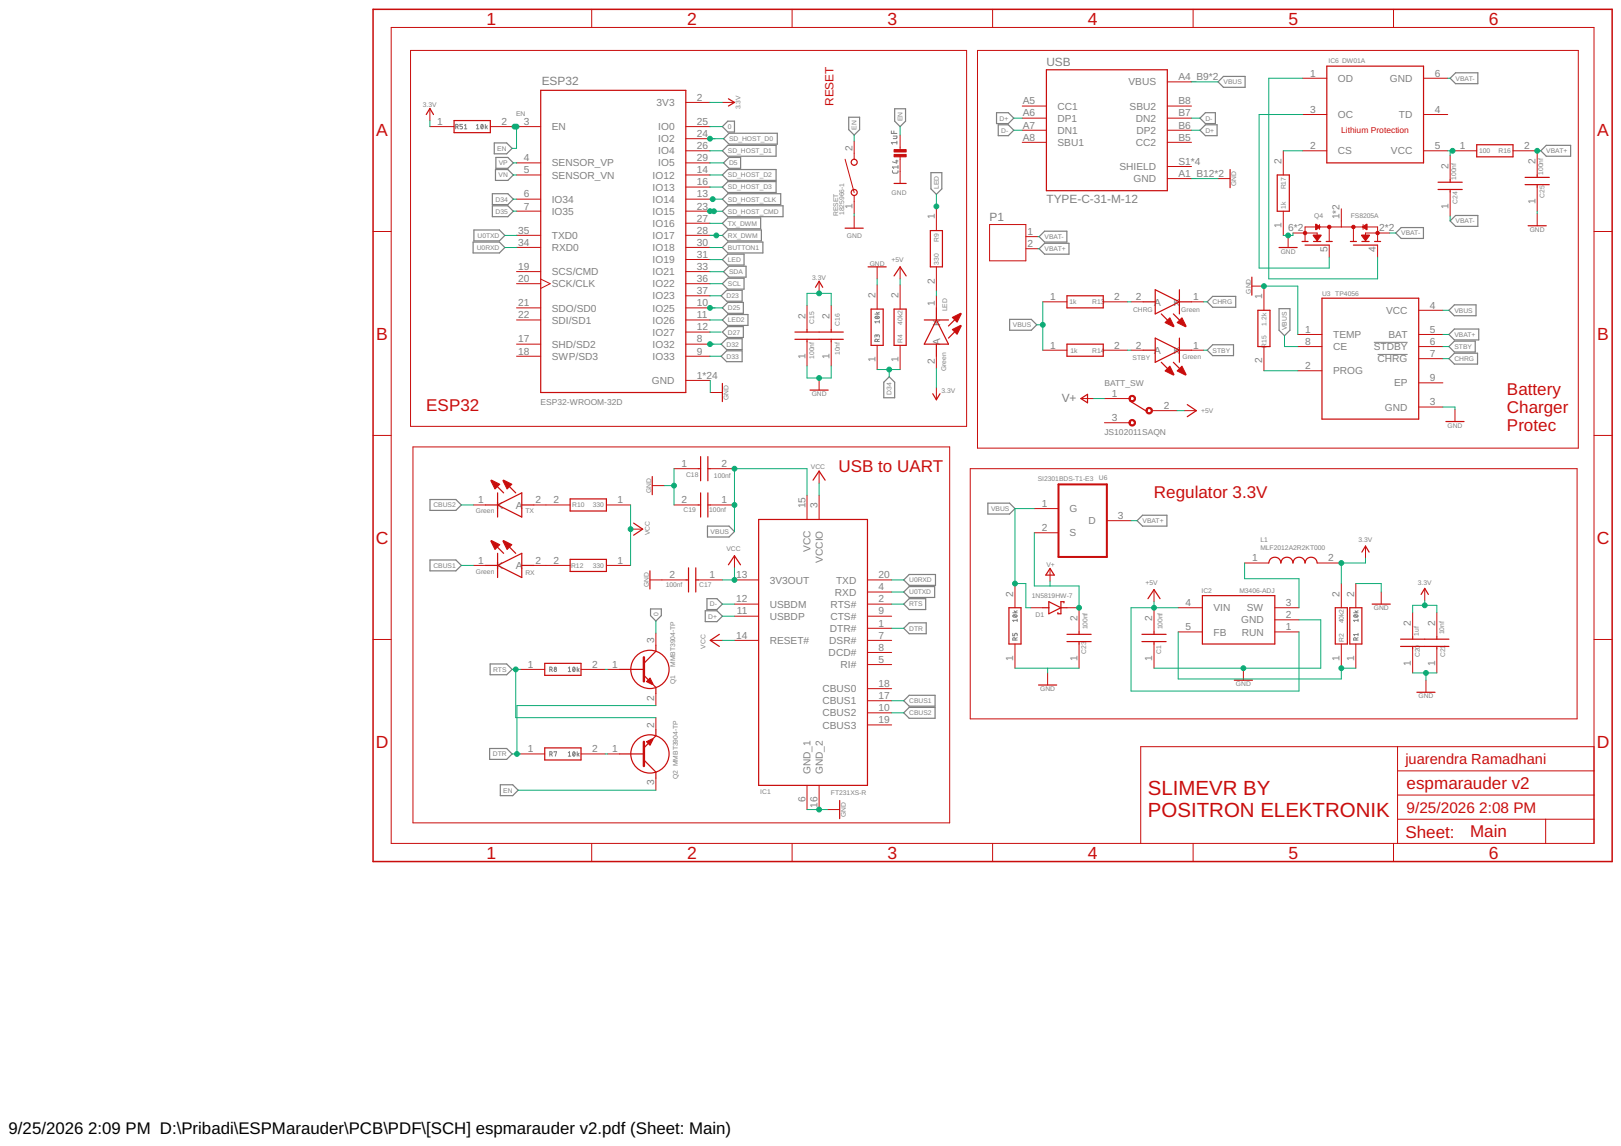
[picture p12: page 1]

9/25/2026 2:09 PM D:\Pribadi\ESPMarauder\PCB\PDF\[SCH] espmarauder v2.pdf (Sheet: Main)

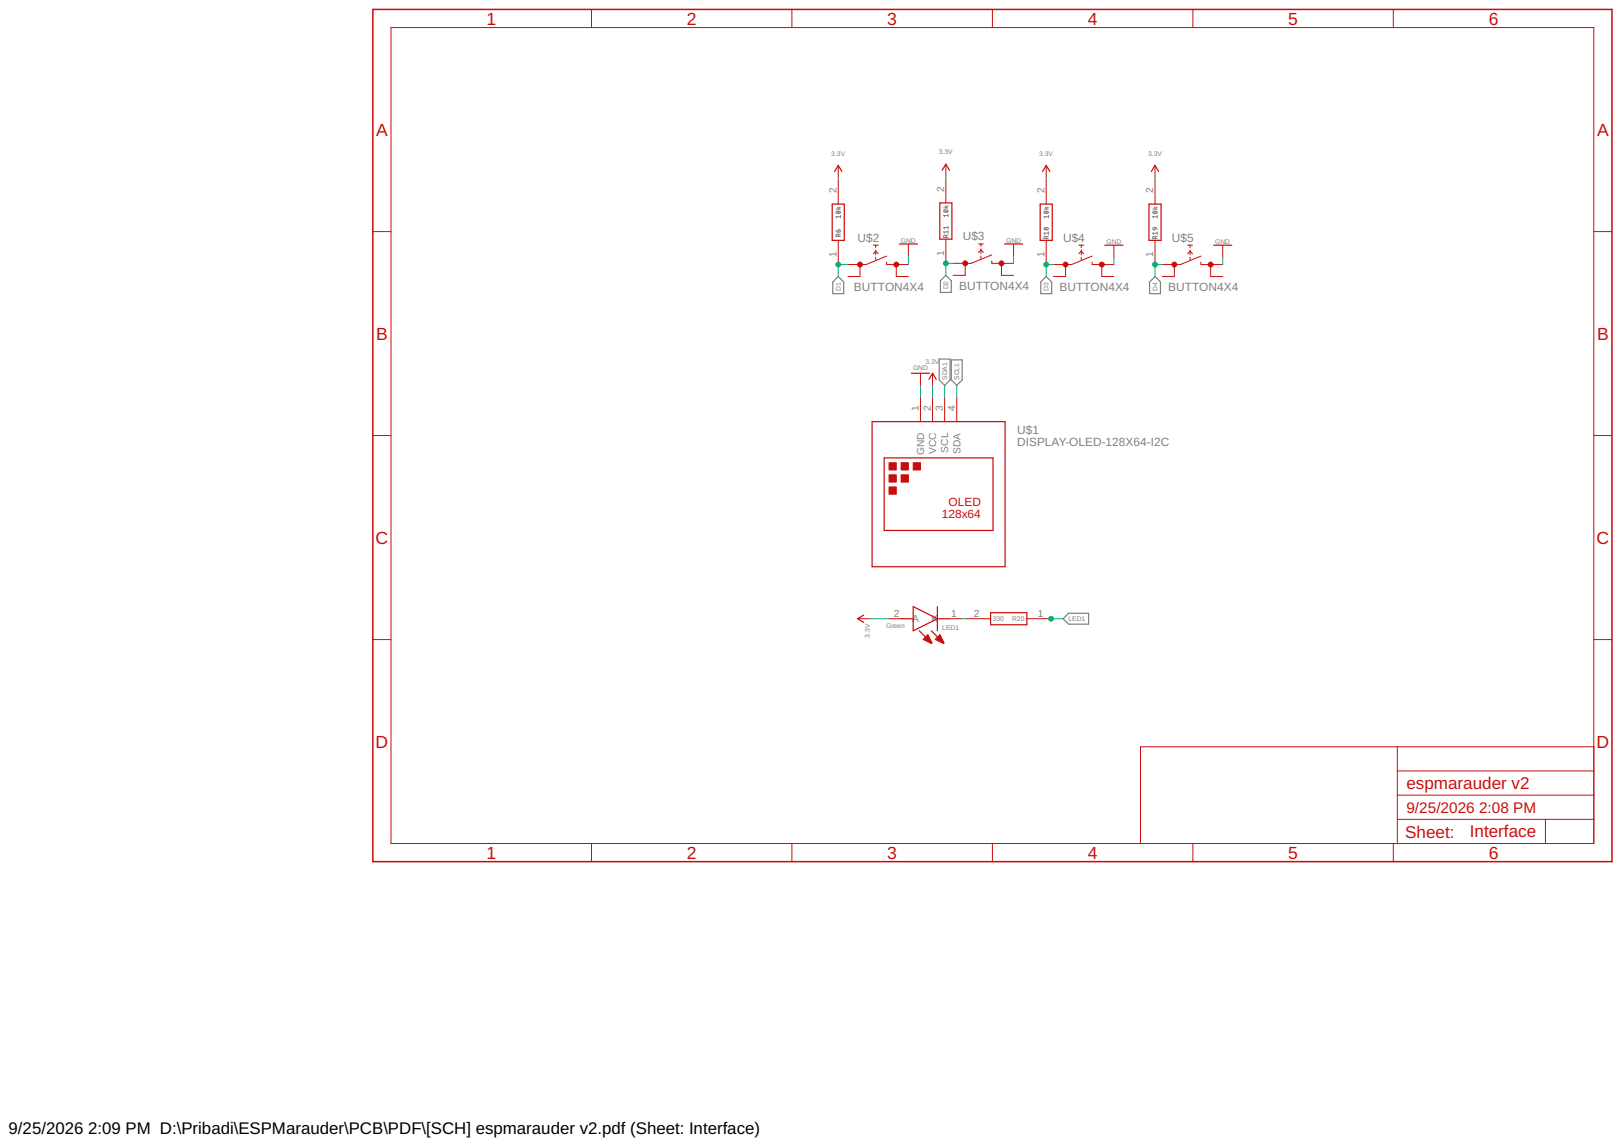
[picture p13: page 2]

9/25/2026 2:09 PM D:\Pribadi\ESPMarauder\PCB\PDF\[SCH] espmarauder v2.pdf (Sheet: Interface)

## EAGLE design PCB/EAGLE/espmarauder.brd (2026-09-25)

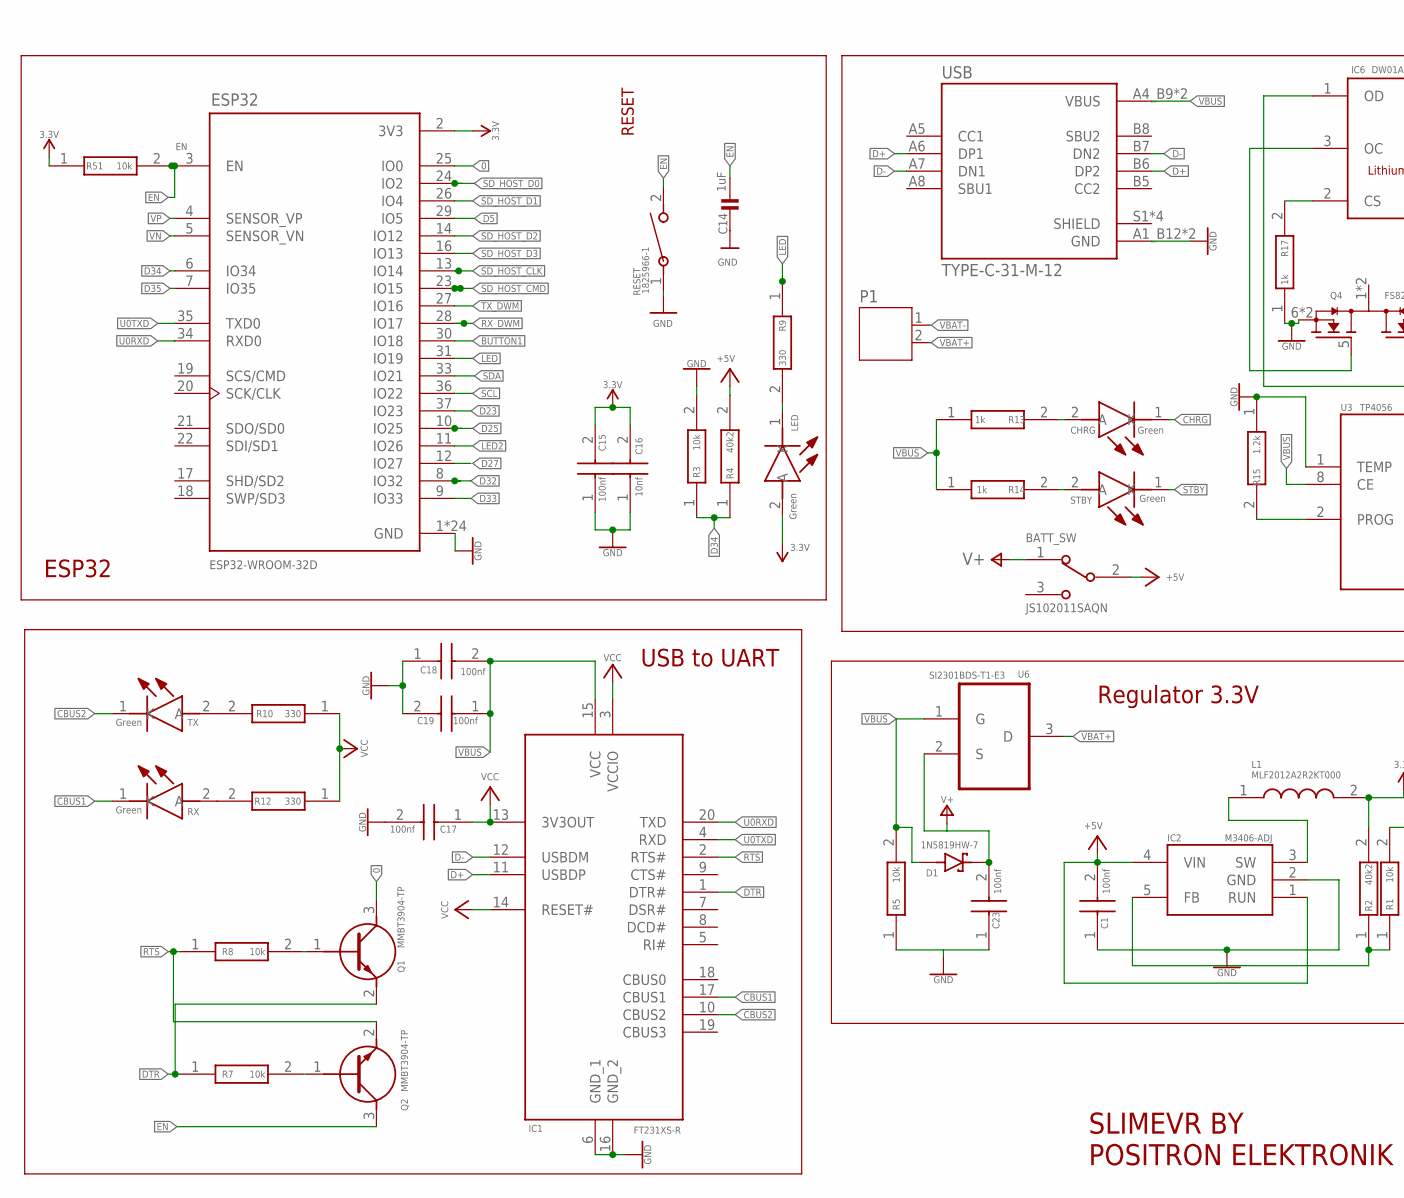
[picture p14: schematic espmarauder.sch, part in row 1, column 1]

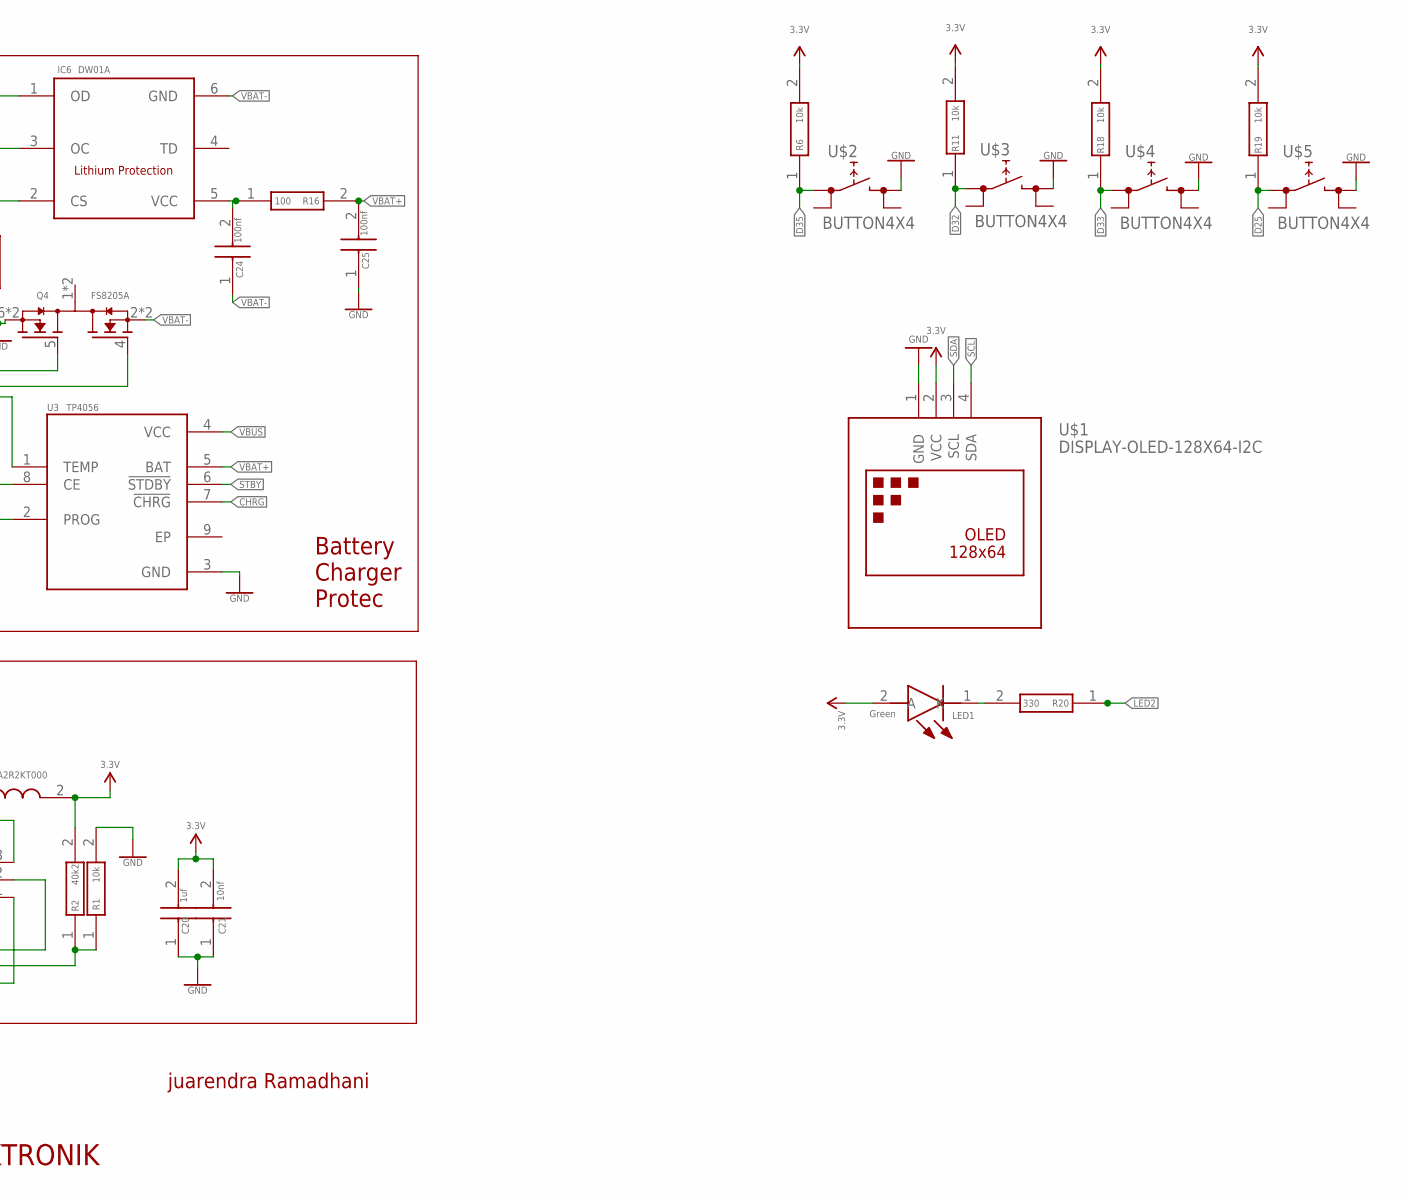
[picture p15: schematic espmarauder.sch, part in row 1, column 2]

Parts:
BATT_SW: JS102011SAQN; SW_JS102011SAQN
C1, C15, C17, C18, C19, C23, C24, C25: 100nf; CAPC1608X87N
C14: 1uF; 0603
C16, C21: 10nf; CAPC1608X87N
C20: 1uf; CAPC1608X87N
CHRG: Green; LEDC2012X80N
D1: 1N5819HW-7; SOD3715X145N
ESP32: ESP32-WROOM-32D; MODULE_ESP32-WROOM-32D
IC1: FT231XS-R; SOP64P599X175-20N
IC2: M3406-ADJ; SOT95P280X100-5N
IC6: DW01A; SOT23-6
L1: MLF2012A2R2KT000; INDC2012X105N
LED, LED1: Green; LEDC2012X80N
P1: JST-PH2
Q1, Q2: MMBT3904-TP; SI2305TP
Q4: FS8205A; SOP65P640X120-8N
R1, R3, R5, R6, R7, R8, R11, R18, R19, R51: 10k; RESC1608X55N
R2, R4: 40k2; RESC1608X55N
R9, R10, R12, R20: 330; ERJH3
R13, R14, R17: 1k; RESC1608X55N
R15: 1.2k; RESC1608X55N
R16: 100; RESC1608X55N
RESET: 1825966-1; SWDIP2_256X170P100
RX: Green; LEDC2012X80N
STBY: Green; LEDC2012X80N
TX: Green; LEDC2012X80N
U3: TP4056; SOP127P600X175-9N
U6: SI2301BDS-T1-E3; SOT95P237X112-3N
U$1: DISPLAY-OLED-128X64-I2C
U$2, U$3, U$4, U$5: BUTTON4X4
USB: TYPE-C-31-M-12; HRO_TYPE-C-31-M-12

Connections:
0: ESP32.25 (IO0), Q1.3 (C)
3.3V: C15.2, C16.2, C20.2, C21.2, ESP32.2 (3V3), L1.2, LED.2 (A), LED1.2 (A), R2.2, R6.2, R11.2, R18.2, R19.2, R51.1, U$1.2 (VCC)
+5V: BATT_SW.2, C1.2, IC2.1 (RUN), IC2.4 (VIN), R4.2
BUTTON1: ESP32.30 (IO18)
CBUS1: IC1.17 (CBUS1), RX.1 (K)
CBUS2: IC1.10 (CBUS2), TX.1 (K)
CHRG: CHRG.1 (K), U3.7 (!CHRG)
D5: ESP32.29 (IO5)
D23: ESP32.37 (IO23)
D25: ESP32.10 (IO25), R19.1, U$5.1
D27: ESP32.12 (IO27)
D32: ESP32.8 (IO32), R11.1, U$3.1
D33: ESP32.9 (IO33), R18.1, U$4.1
D34: ESP32.6 (IO34), R3.1, R4.1
D35: ESP32.7 (IO35), R6.1, U$2.1
D+: IC1.11 (USBDP), USB.A6 (DP1), USB.B6 (DP2)
D-: IC1.12 (USBDM), USB.A7 (DN1), USB.B7 (DN2)
DTR: IC1.1 (DTR#), Q1.2 (E), R7.1
EN: C14.1, ESP32.3 (EN), Q2.3 (C), R51.2, RESET.2
GND: C1.1, C14.2, C15.1, C16.1, C17.2, C18.1, C19.2, C20.1, C21.1, C23.1, C25.1, ESP32.1 (GND), ESP32.15 (GND), ESP32.38 (GND), ESP32.39_1 (GND), ESP32.39_2 (GND), ESP32.39_3 (GND), ESP32.39_4 (GND), ESP32.39_5 (GND), ESP32.39_6 (GND), ESP32.39_7 (GND), ESP32.39_8 (GND), ESP32.39_9 (GND), ESP32.39_10 (GND), ESP32.39_11 (GND), ESP32.39_12 (GND), ESP32.39_13 (GND), ESP32.39_14 (GND), ESP32.39_15 (GND), ESP32.39_16 (GND), ESP32.39_17 (GND), ESP32.39_18 (GND), ESP32.39_19 (GND), ESP32.39_20 (GND), ESP32.39_21 (GND), IC1.6 (GND_1), IC1.16 (GND_2), IC2.2 (GND), Q4.6 (S2), Q4.7 (S2), R1.2, R3.2, R5.1, R15.1, R17.1, RESET.1, U3.1 (TEMP), U3.3 (GND), U$1.1 (GND), U$2.3, U$3.3, U$4.3, U$5.3, USB.A1_B12 (GND), USB.B1_A12 (GND)
LED: ESP32.31 (IO19), R9.1
LED2: ESP32.11 (IO26), R20.1
unnamed: IC2.3 (SW), L1.1
unnamed: LED.1 (K), R9.2
unnamed: IC2.5 (FB), R1.1, R2.1
unnamed: LED1.1 (K), R20.2
unnamed: Q2.1 (B), R7.2
unnamed: Q1.1 (B), R8.2
unnamed: R12.2, RX.2 (A)
unnamed: R10.2, TX.2 (A)
unnamed: CHRG.2 (A), R13.2
unnamed: R14.2, STBY.2 (A)
unnamed: R15.2, U3.2 (PROG)
unnamed: C24.2, IC6.5 (VCC), R16.1
unnamed: IC6.1 (OD), Q4.4 (G1)
unnamed: IC6.2 (CS), R17.2
unnamed: IC6.3 (OC), Q4.5 (G2)
RTS: IC1.2 (RTS#), Q2.2 (E), R8.1
RX_DWM: ESP32.28 (IO17)
SCL: ESP32.36 (IO22), U$1.4 (SDA)
SDA: ESP32.33 (IO21), U$1.3 (SCL)
SD_HOST_CLK: ESP32.13 (IO14)
SD_HOST_CMD: ESP32.23 (IO15)
SD_HOST_D0: ESP32.24 (IO2)
SD_HOST_D1: ESP32.26 (IO4)
SD_HOST_D2: ESP32.14 (IO12)
SD_HOST_D3: ESP32.16 (IO13)
STBY: STBY.1 (K), U3.6 (!STDBY)
TX_DWM: ESP32.27 (IO16)
U0RXD: ESP32.34 (RXD0), IC1.20 (TXD)
U0TXD: ESP32.35 (TXD0), IC1.4 (RXD)
V+: BATT_SW.1, C23.2, D1.C (K), U6.2 (S)
VBAT+: C25.2, P1.2, R16.2, U3.5 (BAT), U6.3 (D)
VBAT-: C24.1, IC6.6 (GND), P1.1, Q4.2 (S1), Q4.3 (S1)
VBUS: C18.2, C19.1, D1.A, IC1.15 (VCC), R5.2, R13.1, R14.1, U3.4 (VCC), U3.8 (CE), U6.1 (G), USB.A4_B9 (VBUS), USB.B4_A9 (VBUS)
VCC: C17.1, IC1.3 (VCCIO), IC1.13 (3V3OUT), IC1.14 (RESET#), R10.1, R12.1
VN: ESP32.5 (SENSOR_VN)
VP: ESP32.4 (SENSOR_VP)

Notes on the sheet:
RESET
ESP32
USB to UART
Battery Charger Protec
Regulator 3.3V
SLIMEVR BY POSITRON ELEKTRONIK
juarendra Ramadhani

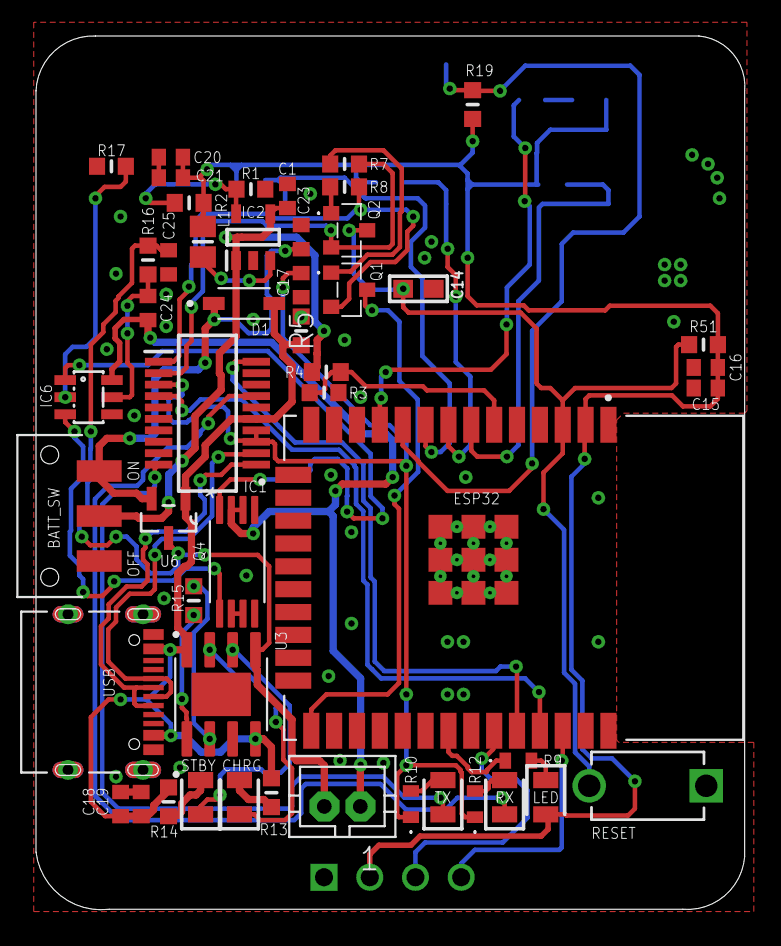
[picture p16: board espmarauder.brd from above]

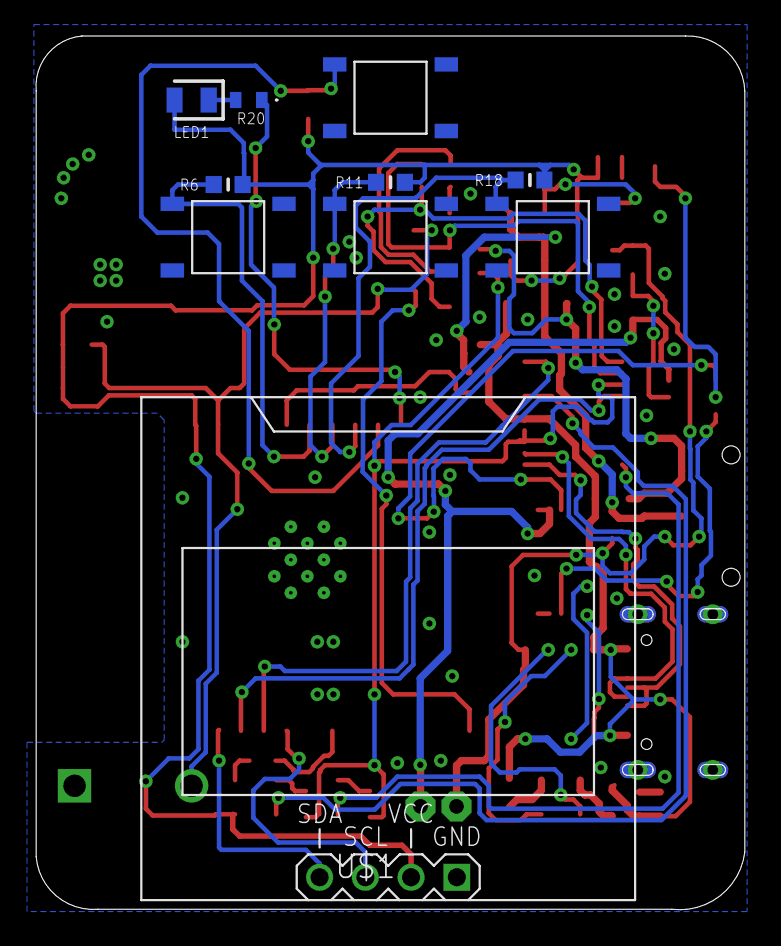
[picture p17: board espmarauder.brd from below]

Board: 2 copper layers, 39.4 x 48.5 mm, 59 parts (10 on the bottom side), 44 nets.

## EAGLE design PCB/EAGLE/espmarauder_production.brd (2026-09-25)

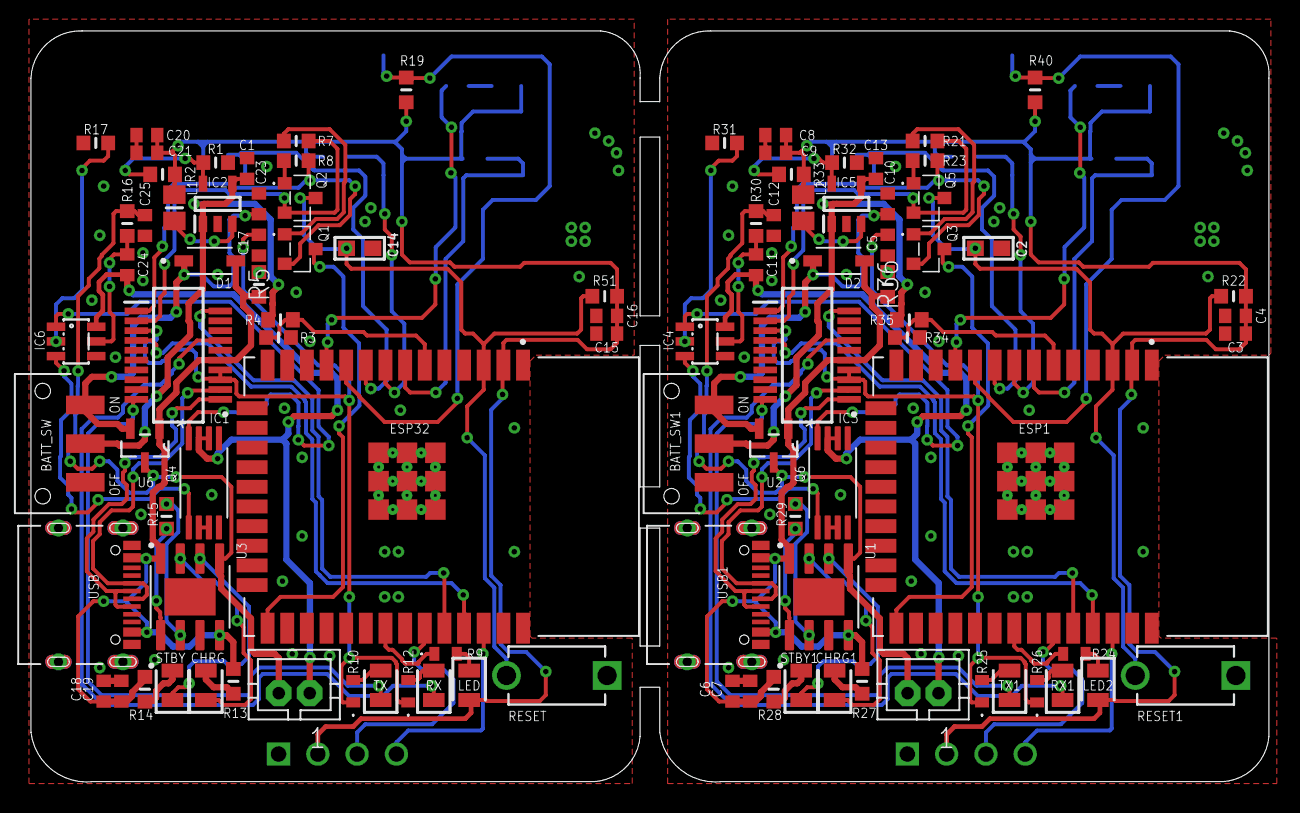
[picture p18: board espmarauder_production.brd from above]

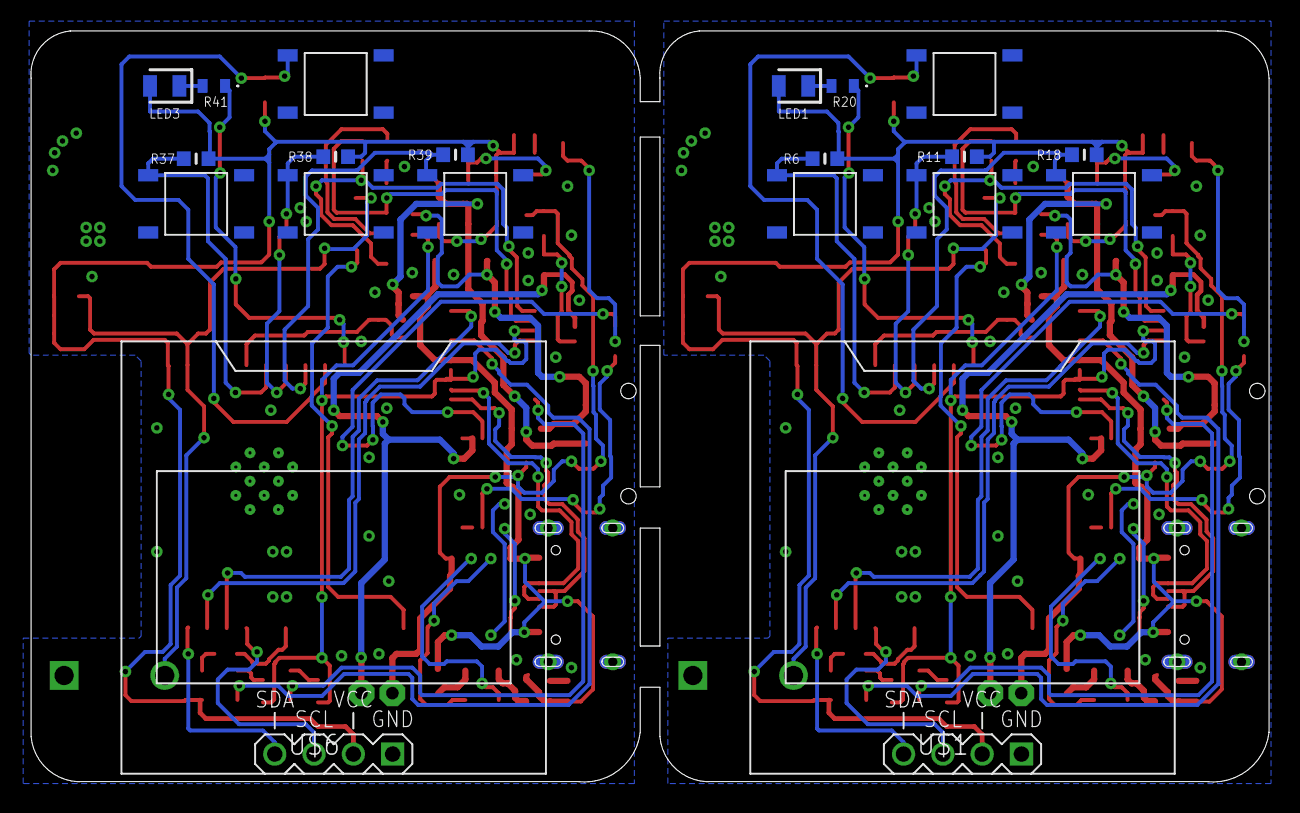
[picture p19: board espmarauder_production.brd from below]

Board: 2 copper layers, 80.0 x 48.5 mm, 118 parts (20 on the bottom side), 88 nets.

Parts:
BATT_SW, BATT_SW1: JS102011SAQN; SW_JS102011SAQN
C1, C3, C5, C6, C7, C10, C11, C12, C13, C15, C17, C18, C19, C23, C24, C25: 100nf; CAPC1608X87N
C2, C14: 1uF; 0603
C4, C9, C16, C21: 10nf; CAPC1608X87N
C8, C20: 1uf; CAPC1608X87N
CHRG, CHRG1: Green; LEDC2012X80N
D1, D2: 1N5819HW-7; SOD3715X145N
ESP1, ESP32: ESP32-WROOM-32D; MODULE_ESP32-WROOM-32D
IC1, IC3: FT231XS-R; SOP64P599X175-20N
IC2, IC5: M3406-ADJ; SOT95P280X100-5N
IC4, IC6: DW01A; SOT23-6
L1, L2: MLF2012A2R2KT000; INDC2012X105N
LED, LED1, LED2, LED3: Green; LEDC2012X80N
P1, P2: JST-PH2
Q1, Q2, Q3, Q5: MMBT3904-TP; SI2305TP
Q4, Q6: FS8205A; SOP65P640X120-8N
R1, R3, R5, R6, R7, R8, R11, R18, R19, R21, R22, R23, R32, R34, R36, R37, R38, R39, R40, R51: 10k; RESC1608X55N
R2, R4, R33, R35: 40k2; RESC1608X55N
R9, R10, R12, R20, R24, R25, R26, R41: 330; ERJH3
R13, R14, R17, R27, R28, R31: 1k; RESC1608X55N
R15, R29: 1.2k; RESC1608X55N
R16, R30: 100; RESC1608X55N
RESET, RESET1: 1825966-1; SWDIP2_256X170P100
RX, RX1: Green; LEDC2012X80N
STBY, STBY1: Green; LEDC2012X80N
TX, TX1: Green; LEDC2012X80N
U1, U3: TP4056; SOP127P600X175-9N
U2, U6: SI2301BDS-T1-E3; SOT95P237X112-3N
U$1, U$6: DISPLAY-OLED-128X64-I2C
U$2, U$3, U$4, U$5, U$7, U$8, U$9, U$10: BUTTON4X4
USB, USB1: TYPE-C-31-M-12; HRO_TYPE-C-31-M-12

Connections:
0: ESP32.25, Q1.3
1: ESP1.25, Q3.3
3.3V: C15.2, C16.2, C20.2, C21.2, ESP32.2, L1.2, LED.2, LED1.2, R2.2, R6.2, R11.2, R18.2, R19.2, R51.1, U$1.2
3.3V1: C3.2, C4.2, C8.2, C9.2, ESP1.2, L2.2, LED2.2, LED3.2, R22.1, R33.2, R37.2, R38.2, R39.2, R40.2, U$6.2
+5V: BATT_SW.2, C1.2, IC2.1, IC2.4, R4.2
+5V1: BATT_SW1.2, C13.2, IC5.1, IC5.4, R35.2
CBUS1: IC1.17, RX.1
CBUS2: IC1.10, TX.1
CBUS3: IC3.17, RX1.1
CBUS4: IC3.10, TX1.1
CHRG: CHRG.1, U3.7
CHRG1: CHRG1.1, U1.7
D1: ESP1.6, R34.1, R35.1
D2: ESP1.7, R37.1, U$7.1
D3: ESP1.8, R38.1, U$8.1
D4: ESP1.9, R39.1, U$9.1
D6: ESP1.10, R40.1, U$10.1
D25: ESP32.10, R19.1, U$5.1
D32: ESP32.8, R11.1, U$3.1
D33: ESP32.9, R18.1, U$4.1
D34: ESP32.6, R3.1, R4.1
D35: ESP32.7, R6.1, U$2.1
D+: IC1.11, USB.A6, USB.B6
D+1: IC3.11, USB1.A6, USB1.B6
D-: IC1.12, USB.A7, USB.B7
D-1: IC3.12, USB1.A7, USB1.B7
DTR: IC1.1, Q1.2, R7.1
DTR1: IC3.1, Q3.2, R21.1
EN: C14.1, ESP32.3, Q2.3, R51.2, RESET.2
EN1: C2.1, ESP1.3, Q5.3, R22.2, RESET1.2
GND: C1.1, C14.2, C15.1, C16.1, C17.2, C18.1, C19.2, C20.1, C21.1, C23.1, C25.1, ESP32.1, ESP32.15, ESP32.38, ESP32.39_1, ESP32.39_2, ESP32.39_3, ESP32.39_4, ESP32.39_5, ESP32.39_6, ESP32.39_7, ESP32.39_8, ESP32.39_9, ESP32.39_10, ESP32.39_11, ESP32.39_12, ESP32.39_13, ESP32.39_14, ESP32.39_15, ESP32.39_16, ESP32.39_17, ESP32.39_18, ESP32.39_19, ESP32.39_20, ESP32.39_21, IC1.6, IC1.16, IC2.2, Q4.6, Q4.7, R1.2, R3.2, R5.1, R15.1, R17.1, RESET.1, U3.1, U3.3, U$1.1, U$2.3, U$3.3, U$4.3, U$5.3, USB.A1_B12, USB.B1_A12
GND1: C2.2, C3.1, C4.1, C5.2, C6.1, C7.2, C8.1, C9.1, C10.1, C12.1, C13.1, ESP1.1, ESP1.15, ESP1.38, ESP1.39_1, ESP1.39_2, ESP1.39_3, ESP1.39_4, ESP1.39_5, ESP1.39_6, ESP1.39_7, ESP1.39_8, ESP1.39_9, ESP1.39_10, ESP1.39_11, ESP1.39_12, ESP1.39_13, ESP1.39_14, ESP1.39_15, ESP1.39_16, ESP1.39_17, ESP1.39_18, ESP1.39_19, ESP1.39_20, ESP1.39_21, IC3.6, IC3.16, IC5.2, Q6.6, Q6.7, R29.1, R31.1, R32.2, R34.2, R36.1, RESET1.1, U1.1, U1.3, U$6.1, U$7.3, U$8.3, U$9.3, U$10.3, USB1.A1_B12, USB1.B1_A12
LED: ESP32.31, R9.1
LED1: ESP1.11, R41.1
LED2: ESP32.11, R20.1
LED3: ESP1.31, R24.1
unnamed: IC2.3, L1.1
unnamed: LED.1, R9.2
unnamed: IC2.5, R1.1, R2.1
unnamed: LED1.1, R20.2
unnamed: Q5.1, R21.2
unnamed: Q3.1, R23.2
unnamed: R26.2, RX1.2
unnamed: R25.2, TX1.2
unnamed: Q2.1, R7.2
unnamed: CHRG1.2, R27.2
unnamed: Q1.1, R8.2
unnamed: R12.2, RX.2
unnamed: R10.2, TX.2
unnamed: R28.2, STBY1.2
unnamed: CHRG.2, R13.2
unnamed: R14.2, STBY.2
unnamed: R29.2, U1.2
unnamed: R15.2, U3.2
unnamed: C24.2, IC6.5, R16.1
unnamed: IC6.1, Q4.4
unnamed: IC6.2, R17.2
unnamed: C11.2, IC4.5, R30.1
unnamed: IC4.1, Q6.4
unnamed: IC4.2, R31.2
unnamed: IC4.3, Q6.5
unnamed: IC6.3, Q4.5
unnamed: IC5.3, L2.1
unnamed: IC5.5, R32.1, R33.1
unnamed: LED2.1, R24.2
unnamed: LED3.1, R41.2
RTS: IC1.2, Q2.2, R8.1
RTS1: IC3.2, Q5.2, R23.1
SCL: ESP32.36, U$1.4
SCL1: ESP1.36, U$6.4
SDA: ESP32.33, U$1.3
SDA1: ESP1.33, U$6.3
STBY: STBY.1, U3.6
STBY1: STBY1.1, U1.6
U0RXD: ESP32.34, IC1.20
U0RXD1: ESP1.34, IC3.20
U0TXD: ESP32.35, IC1.4
U0TXD1: ESP1.35, IC3.4
V+: BATT_SW.1, C23.2, D1.C, U6.2
V+1: BATT_SW1.1, C10.2, D2.C, U2.2
VBAT+: C25.2, P1.2, R16.2, U3.5, U6.3
VBAT+1: C12.2, P2.2, R30.2, U1.5, U2.3
VBAT-: C24.1, IC6.6, P1.1, Q4.2, Q4.3
VBAT-1: C11.1, IC4.6, P2.1, Q6.2, Q6.3
VBUS: C18.2, C19.1, D1.A, IC1.15, R5.2, R13.1, R14.1, U3.4, U3.8, U6.1, USB.A4_B9, USB.B4_A9
VBUS1: C6.2, C7.1, D2.A, IC3.15, R27.1, R28.1, R36.2, U1.4, U1.8, U2.1, USB1.A4_B9, USB1.B4_A9
VCC: C17.1, IC1.3, IC1.13, IC1.14, R10.1, R12.1
VCC1: C5.1, IC3.3, IC3.13, IC3.14, R25.1, R26.1

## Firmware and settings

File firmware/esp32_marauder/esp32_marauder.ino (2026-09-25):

/* FLASH SETTINGS
Board: LOLIN D32
 Frequency: 80MHz
Partition Scheme: Minimal SPIFFS
https://www.online-utility.org/image/convert/to/XBM
*/

#include "configs.h"

#ifndef HAS_SCREEN
  #define MenuFunctions_h
  #define Display_h
#endif

#include <stdio.h>

#ifdef HAS_GPS
  #include "GpsInterface.h"
#endif

#include "Assets.h"
#include "WiFiScan.h"
#ifdef HAS_SD
  #include "SDInterface.h"
#endif
#include "Buffer.h"

#ifdef HAS_FLIPPER_LED
  #include "flipperLED.h"
#elif defined(XIAO_ESP32_S3)
  #include "xiaoLED.h"
#elif defined(MARAUDER_M5STICKC) || defined(MARAUDER_M5STICKCP2)
  #include "stickcLED.h"
#elif defined(HAS_NEOPIXEL_LED) || defined(HAS_T_DONGLE_LED)
  #include "LedInterface.h"
#endif

#include "settings.h"
#include "CommandLine.h"
#include "ReconMission.h"
#include "lang_var.h"

#ifdef HAS_T_DONGLE_DISPLAY
  #include "TDongleDisplay.h"
#endif

#ifdef HAS_BATTERY
  #include "BatteryInterface.h"
#endif

#ifdef HAS_SCREEN
  #include "Display.h"
  #include "MenuFunctions.h"
#endif

#ifdef HAS_BUTTONS
  #include "Switches.h"
  
  #if (U_BTN >= 0)
    Switches u_btn = Switches(U_BTN, 1000, U_PULL);
  #endif
  #if (D_BTN >= 0)
    Switches d_btn = Switches(D_BTN, 1000, D_PULL);
  #endif
  #if (L_BTN >= 0)
    Switches l_btn = Switches(L_BTN, 1000, L_PULL);
  #endif
  #if (R_BTN >= 0)
    Switches r_btn = Switches(R_BTN, 1000, R_PULL);
  #endif
  #if (C_BTN >= 0)
    Switches c_btn = Switches(C_BTN, 1000, C_PULL);
  #endif

#endif

WiFiScan wifi_scan_obj;
EvilPortal evil_portal_obj;
Buffer buffer_obj;
Settings settings_obj;
CommandLine cli_obj;
ReconMission recon_obj;

#ifdef HAS_T_DONGLE_DISPLAY
  TDongleDisplay t_dongle_display;
#endif

#ifdef HAS_GPS
  GpsInterface gps_obj;
#endif

#ifdef HAS_BATTERY
  BatteryInterface battery_obj;
#endif

#ifdef HAS_SCREEN
  Display display_obj;
  MenuFunctions menu_function_obj;
#endif

#if defined(HAS_SD) && !defined(HAS_C5_SD)
  SDInterface sd_obj;
#endif

#ifdef HAS_FLIPPER_LED
  flipperLED flipper_led;
#elif defined(XIAO_ESP32_S3)
  xiaoLED xiao_led;
#elif defined(MARAUDER_M5STICKC) || defined(MARAUDER_M5STICKCP2)
  stickcLED stickc_led;
#elif defined(HAS_NEOPIXEL_LED) || defined(HAS_T_DONGLE_LED)
  LedInterface led_obj;
#endif

const String PROGMEM version_number = MARAUDER_VERSION;

#ifdef HAS_NEOPIXEL_LED
  Adafruit_NeoPixel strip = Adafruit_NeoPixel(Pixels, PIN, NEO_GRB + NEO_KHZ800);
#endif

uint32_t currentTime  = 0;

// PWM Brightness Control
#ifdef HAS_SCREEN
  #include <Preferences.h>
  #define BL_CHANNEL 0
  #define BL_FREQ 5000
  #define BL_RESOLUTION 8
  const uint8_t BL_LEVELS[] = {26, 51, 77, 102, 128, 153, 179, 204, 230, 255};
  const uint8_t BL_NUM_LEVELS = 10;
  uint8_t bl_level_idx = 9; // default full brightness
  Preferences bl_prefs;
#endif

// Helper macros for LEDC API compatibility (2.x vs 3.x board package)
#ifdef HAS_SCREEN
  #ifndef HAS_MINI_SCREEN
    #if ESP_ARDUINO_VERSION_MAJOR >= 3
      #define BL_SETUP()       ledcAttach(TFT_BL, BL_FREQ, BL_RESOLUTION)
      #define BL_SET(duty)     ledcWrite(TFT_BL, (duty))
    #else
      #define BL_SETUP()       do { ledcSetup(BL_CHANNEL, BL_FREQ, BL_RESOLUTION); ledcAttachPin(TFT_BL, BL_CHANNEL); } while(0)
      #define BL_SET(duty)     ledcWrite(BL_CHANNEL, (duty))
    #endif
  #endif
#endif

#ifndef HAS_MINI_SCREEN
  void brightnessInit() {
    #ifdef HAS_SCREEN
      BL_SETUP();
      bl_prefs.begin("backlight", false);
      bl_level_idx = bl_prefs.getUChar("level", 9);
      if (bl_level_idx >= BL_NUM_LEVELS) bl_level_idx = 9;
      BL_SET(BL_LEVELS[bl_level_idx]);
    #endif
  }

  void brightnessCycle() {
    #ifdef HAS_SCREEN
      bl_level_idx = (bl_level_idx + 1) % BL_NUM_LEVELS;
      BL_SET(BL_LEVELS[bl_level_idx]);
      bl_prefs.putUChar("level", bl_level_idx);
      Serial.print(F("[Brightness] Level "));
      Serial.print(bl_level_idx + 1);
      Serial.print(F("/"));
      Serial.print(BL_NUM_LEVELS);
      Serial.print(F(" ("));
      Serial.print(BL_LEVELS[bl_level_idx] * 100 / 255);
      Serial.println(F("%)"));
    #endif
  }

  uint8_t getBrightnessLevel() {
    #ifdef HAS_SCREEN
      return bl_level_idx;
    #else
      return 0;
    #endif
  }

  void brightnessSave(uint8_t level) {
    #ifdef HAS_SCREEN
      if (level >= BL_NUM_LEVELS) level = BL_NUM_LEVELS - 1;
      bl_level_idx = level;
      BL_SET(BL_LEVELS[bl_level_idx]);
      bl_prefs.putUChar("level", bl_level_idx);
    #endif
  }

  void backlightOn() {
    #ifdef HAS_SCREEN
      BL_SET(BL_LEVELS[bl_level_idx]);
    #endif
  }

  void backlightOff() {
    #ifdef HAS_SCREEN
      BL_SET(0);
    #endif
  }
#else
  void backlightOn() {
    #ifdef HAS_SCREEN
      #if defined(MARAUDER_MINI) || defined(MARAUDER_MINI_V3)
        digitalWrite(TFT_BL, LOW);
      #endif
    
      #if !defined(MARAUDER_MINI) && !defined(MARAUDER_MINI_V3)
        digitalWrite(TFT_BL, HIGH);
      #endif
    #endif
  }

  void backlightOff() {
    #ifdef HAS_SCREEN
      #if defined(MARAUDER_MINI) || defined(MARAUDER_MINI_V3)
        digitalWrite(TFT_BL, HIGH);
      #endif
    
      #if !defined(MARAUDER_MINI) && !defined(MARAUDER_MINI_V3)
        digitalWrite(TFT_BL, LOW);
      #endif
    #endif
  }
#endif

#ifdef HAS_C5_SD
  SPIClass sharedSPI(SPI);
  SDInterface sd_obj = SDInterface(&sharedSPI, SD_CS);
#endif

void setup()
{
  randomSeed(esp_random());
  
  #ifndef DEVELOPER
    esp_log_level_set("*", ESP_LOG_NONE);
  #endif
  
  #ifndef HAS_IDF_3
    esp_spiram_init();
  #endif

  Serial.begin(115200);

  #ifdef HAS_ACT_LED
    pinMode(ACT_LED_PIN, OUTPUT);
    delay(100);
    digitalWrite(ACT_LED_PIN, ACT_LED_OFF);
  #endif

  while(!Serial)
    delay(10);

  #ifdef HAS_C5_SD
    sharedSPI.begin(SD_SCK, SD_MISO, SD_MOSI);
    delay(100);
  #endif

  #if defined(MARAUDER_M5STICKCP2) // Prevent StickCP2 from turning off when disconnect USB cable
    pinMode(POWER_HOLD_PIN, OUTPUT);
    digitalWrite(POWER_HOLD_PIN, HIGH);
  #endif
  
  #ifdef HAS_SCREEN
    pinMode(TFT_BL, OUTPUT);
  #endif
  
  backlightOff();
  #if BATTERY_ANALOG_ON == 1
    pinMode(BATTERY_PIN, OUTPUT);
    pinMode(CHARGING_PIN, INPUT);
  #endif
  
  // Preset SPI CS pins to avoid bus conflicts
  #ifdef HAS_SCREEN
    digitalWrite(TFT_CS, HIGH);
  #endif
  
  #if defined(HAS_SD) && !defined(HAS_C5_SD)
    pinMode(SD_CS, OUTPUT);

    delay(10);
  
    digitalWrite(SD_CS, HIGH);

    delay(10);
  #endif

  //Serial.begin(115200);

  //while(!Serial)
  //  delay(10);

  Serial.println("ESP-IDF version is: " + String(esp_get_idf_version()));

  #ifdef HAS_PSRAM
    if (!psramInit()) {
      Serial.println(F("PSRAM not available"));
    }
  #endif

  #ifdef HAS_SIMPLEX_DISPLAY
    #if defined(HAS_SD)
      // Do some SD stuff
      if(!sd_obj.initSD())
        Serial.println(F("SD Card NOT Supported"));

    #endif
  #endif

  #ifdef HAS_SCREEN
    display_obj.RunSetup();
    display_obj.tft.setTextColor(TFT_WHITE, TFT_BLACK);
  #endif

  // Init PWM brightness AFTER display init (so ledcAttach overrides TFT_eSPI's pinMode)
  #ifndef HAS_MINI_SCREEN
    brightnessInit();
    backlightOff();
  #endif

  #ifdef HAS_SCREEN
    display_obj.drawBootSplash();
  #endif


  backlightOn(); // Need this

  #ifdef HAS_SCREEN
    // Do some stealth mode stuff
    #ifdef HAS_BUTTONS
      if (c_btn.justPressed()) {
        display_obj.headless_mode = true;

        backlightOff();
      }
    #endif
  #endif

  settings_obj.begin();

  const char* type = settings_obj.getSettingType("wu");

  if (type == nullptr || type[0] == '\0') {
    Serial.println(F("Current settings format not supported. Installing new default settings..."));
    settings_obj.createDefaultSettings(SPIFFS);
  }

  buffer_obj = Buffer();

  #ifndef HAS_SIMPLEX_DISPLAY
    #if defined(HAS_SD)
      // Do some SD stuff
      if(!sd_obj.initSD())
        Serial.println(F("SD Card NOT Supported"));

    #endif
  #endif

  wifi_scan_obj.RunSetup();

  #ifdef HAS_T_DONGLE_DISPLAY
    t_dongle_display.begin();
  #endif

  evil_portal_obj.setup();

  #ifdef HAS_BATTERY
    battery_obj.RunSetup();
  #endif

  #ifdef HAS_BATTERY
    battery_obj.battery_level = battery_obj.getBatteryLevel();
  #endif

  // Do some LED stuff
  #ifdef HAS_FLIPPER_LED
    flipper_led.RunSetup();
  #elif defined(XIAO_ESP32_S3)
    xiao_led.RunSetup();
  #elif defined(MARAUDER_M5STICKC)
    stickc_led.RunSetup();
  #elif defined(HAS_NEOPIXEL_LED) || defined(HAS_T_DONGLE_LED)
    led_obj.RunSetup();
  #endif

  #ifdef HAS_GPS
    gps_obj.begin();
  #endif

  #ifdef HAS_SCREEN  
    display_obj.tft.setTextColor(TFT_WHITE, TFT_BLACK);
  #endif

  #ifdef HAS_SCREEN
    #if defined(MARAUDER_CARDPUTER) || defined(MARAUDER_CARDPUTER_ADV)
      display_obj.clearScreen();
    #endif
    menu_function_obj.RunSetup();
  #endif

  /*char ssidBuf[64] = {0};  // or prefill with existing SSID
  if (keyboardInput(ssidBuf, sizeof(ssidBuf), "Enter SSID")) {
    // user pressed OK
    Serial.println(ssidBuf);
  } else {
    Serial.println(F("User exited keyboard"));
  }

  menu_function_obj.changeMenu(menu_function_obj.current_menu);*/

  wifi_scan_obj.StartScan(WIFI_SCAN_OFF);
  
  cli_obj.RunSetup();
}


void loop()
{
  currentTime = millis();
  bool mini = false;

  #ifdef SCREEN_BUFFER
    #ifndef HAS_ILI9341
      mini = true;
    #endif
  #endif

  #if (defined(HAS_ILI9341) && !defined(MARAUDER_CYD_2USB))
    #ifdef HAS_BUTTONS
      if (c_btn.isHeld()) {
        if (menu_function_obj.disable_touch)
          menu_function_obj.disable_touch = false;
        else
          menu_function_obj.disable_touch = true;

        menu_function_obj.updateStatusBar();

        while (!c_btn.justReleased())
          delay(1);
      }
    #endif
  #endif

  // Update all of our objects
  cli_obj.main(currentTime);
  wifi_scan_obj.main(currentTime);
  recon_obj.main(currentTime);

  #ifdef HAS_T_DONGLE_DISPLAY
    t_dongle_display.update(currentTime, wifi_scan_obj);
  #endif

  #ifdef HAS_GPS
    gps_obj.main();
  #endif

  // Save buffer to SD and/or serial
  buffer_obj.save();

  #ifdef HAS_BATTERY
    battery_obj.main(currentTime);
  #endif
  if ((wifi_scan_obj.currentScanMode != WIFI_PACKET_MONITOR) ||
      (mini)) {
    #ifdef HAS_SCREEN
      menu_function_obj.main(currentTime);
    #endif
  }
  #ifdef HAS_FLIPPER_LED
    flipper_led.main();
  #elif defined(XIAO_ESP32_S3)
    xiao_led.main();
  #elif defined(MARAUDER_M5STICKC)
    stickc_led.main();
  #elif defined(HAS_T_DONGLE_LED)
    // The LED shares GPIO2/GPIO7 with the display/SD bus. Always make it the
    // final writer so later SPI activity cannot leave it latched white.
    led_obj.refresh();
  #elif defined(HAS_NEOPIXEL_LED)
    led_obj.main(currentTime);
  #endif

  #ifdef HAS_SCREEN
    delay(1);
  #else
    delay(50);
  #endif
}

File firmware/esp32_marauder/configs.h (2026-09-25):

#pragma once

#ifndef configs_h

  #define configs_h

  #define POLISH_POTATO

  //#define DEVELOPER

  // Developer-only escape hatch for unsigned or mismatched SD update images.
  // Production builds must remain fail-closed.
  //#define ALLOW_UNVERIFIED_SD_UPDATE

  //// BOARD TARGETS
  //#define MARAUDER_M5STICKC
  //#define MARAUDER_M5STICKCP2
  //#define MARAUDER_MINI
  //#define MARAUDER_V4
  //#define MARAUDER_V6
  //#define MARAUDER_V6_1
  //#define MARAUDER_V7
  //#define MARAUDER_V7_1
  //#define MARAUDER_KIT
  //#define GENERIC_ESP32
  //#define MARAUDER_FLIPPER
  //#define MARAUDER_MULTIBOARD_S3
  //#define ESP32_LDDB
  //#define MARAUDER_DEV_BOARD_PRO
  //#define XIAO_ESP32_S3
  //#define MARAUDER_REV_FEATHER
  //#define MARAUDER_CYD_MICRO // 2432S028
  //#define MARAUDER_CYD_2USB // Another 2432S028 but it has tWo UsBs OoOoOoO
  //#define MARAUDER_CYD_GUITION // ESP32-2432S024 GUITION
  //#define MARAUDER_CYD_3_5_INCH
  //#define MARAUDER_C5
  //#define MARAUDER_T_DONGLE_C5
  //#define MARAUDER_CARDPUTER
  //#define MARAUDER_CARDPUTER_ADV
  //#define MARAUDER_V8
  //#define MARAUDER_PANCAKE
  //#define MARAUDER_MINI_V3
  //#define MARAUDER_M5_NANO_C6
  //#define DUAL_MINI_C5
  //#define POCKET_MARAUDER  // custom board: ESP32-WROOM-32D + SSD1306 OLED + 4 buttons

  // Active target for this repo. Comment out to build a stock Marauder variant above.
  #define POCKET_MARAUDER
  //// END BOARD TARGETS

  // Allocated only while settings are loaded or updated. This accommodates
  // five saved WiFi profiles without permanently caching their passwords.
  #define JSON_SETTING_SIZE 6144

#define MARAUDER_VERSION "v1.17.0"

  #define GRAPH_REFRESH   100

  #define TRACK_EVICT_SEC 90 // Seconds before marking tracked MAC as tombstone

  #define DUAL_BAND_CHANNELS 51

  #define DISPLAY_BUFFER_LIMIT 20

  #define MODE_OFF 0
  #define MODE_RAINBOW 1
  #define MODE_ATTACK 2
  #define MODE_SNIFF 3
  #define MODE_CUSTOM 4

  //// HARDWARE NAMES
  #ifdef MARAUDER_M5STICKC
    #define HARDWARE_NAME "M5Stick-C Plus"
  #elif defined(MARAUDER_M5STICKCP2)
    #define HARDWARE_NAME "M5Stick-C Plus2"
  #elif defined(MARAUDER_CARDPUTER)
    #define HARDWARE_NAME "M5 Cardputer"
  #elif defined(MARAUDER_CARDPUTER_ADV)
    #define HARDWARE_NAME "M5 Cardputer ADV"
  #elif defined(MARAUDER_MINI)
    #define HARDWARE_NAME "Marauder Mini"
  #elif defined(MARAUDER_V7)
    #define HARDWARE_NAME "Marauder v7"
  #elif defined(MARAUDER_V7_1)
    #define HARDWARE_NAME "Marauder v7.1"
  #elif defined(MARAUDER_REV_FEATHER)
    #define HARDWARE_NAME "Adafruit Feather ESP32-S2 Reverse TFT"
  #elif defined(MARAUDER_V4)
    #define HARDWARE_NAME "Marauder v4"
  #elif defined(MARAUDER_V6)
    #define HARDWARE_NAME "Marauder v6"
  #elif defined(MARAUDER_V6_1)
    #define HARDWARE_NAME "Marauder v6.1"
  #elif defined(MARAUDER_CYD_MICRO)
    #define HARDWARE_NAME "CYD 2432S028"
  #elif defined(MARAUDER_CYD_2USB)
    #define HARDWARE_NAME "CYD 2432S028 2USB"
  #elif defined(MARAUDER_CYD_3_5_INCH)
    #define HARDWARE_NAME "CYD 3.5inch"
  #elif defined(MARAUDER_CYD_GUITION)
    #define HARDWARE_NAME "CYD 2432S024 GUITION"
  #elif defined(MARAUDER_KIT)
    #define HARDWARE_NAME "Marauder Kit"
  #elif defined(MARAUDER_FLIPPER)
    #define HARDWARE_NAME "Flipper Zero Dev Board"
  #elif defined(MARAUDER_MULTIBOARD_S3)
    #define HARDWARE_NAME "Flipper Zero Multi Board S3"
  #elif defined(ESP32_LDDB)
    #define HARDWARE_NAME "ESP32 LDDB"
  #elif defined(MARAUDER_DEV_BOARD_PRO)
    #define HARDWARE_NAME "Flipper Zero Dev Board Pro"
  #elif defined(XIAO_ESP32_S3)
    #define HARDWARE_NAME "XIAO ESP32 S3"
  #elif defined(MARAUDER_C5)
    #define HARDWARE_NAME "ESP32-C5 DevKit"
  #elif defined(MARAUDER_T_DONGLE_C5)
    #define HARDWARE_NAME "LilyGo T-Dongle C5"
  #elif defined(MARAUDER_V8)
    #define HARDWARE_NAME "Marauder v8"
  #elif defined(MARAUDER_PANCAKE)
    #define HARDWARE_NAME "Pancake Marauder V8"
  #elif defined(MARAUDER_MINI_V3)
    #define HARDWARE_NAME "Marauder Mini v3"
  #elif defined(DUAL_MINI_C5)
    #define HARDWARE_NAME "Dual Mini C5"
  #elif defined(MARAUDER_M5_NANO_C6)
    #define HARDWARE_NAME "M5 Nano C6"
  #elif defined(POCKET_MARAUDER)
    #define HARDWARE_NAME "PocketMarauder"
  #else
    #define HARDWARE_NAME "ESP32"
  #endif

  //// END HARDWARE NAMES

 //// BOARD FEATURES
  #if defined(DUAL_MINI_C5)
    #define MARAUDER_MINI_V3
  #endif

  #ifdef POCKET_MARAUDER
    #define HAS_BT
    #define HAS_BUTTONS
    #define HAS_SCREEN
    #define HAS_MINI_SCREEN
    #define HAS_NIMBLE_2
    #define HAS_IDF_3
    #define HAS_BATTERY
    #define BATTERY_ADC_PIN 34   // IO34/ADC1_CH6: R3=10k / R4=40.2k divider off switched cell (net +5V)
    #define BATTERY_ADC_MULTIPLIER_X100 502  // (10k+40.2k)/10k = 5.02x, x100 for integer math
    #define HAS_ACT_LED          // green LED on IO19, active-low
    // No SD, GPS, or temp sensor on this board.
  #endif
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

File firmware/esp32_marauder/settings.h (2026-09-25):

#pragma once

#ifndef Settings_h
#define Settings_h

#include "configs.h"

#include "SPIFFS.h"
#include <FS.h>
#include <ArduinoJson.h>

#define FORMAT_SPIFFS_IF_FAILED true

#ifdef HAS_SCREEN
  #include "Display.h"

  extern Display display_obj;
#endif

#define WDG_KEY_NAME       "wdg_key"   // WDG Wars API key (String)
#define SAVED_WIFI_KEY_NAME "SavedWiFi"
#define MAX_SAVED_WIFI_PROFILES 5
#define GEOFENCES_KEY_NAME "Geofences"
#define MAX_GEOFENCES 5
#define GEOFENCE_NAME_MAX 32

struct GeofenceConfig {
  bool enabled = false;
  double latitude = 0;
  double longitude = 0;
  float radiusMiles = 0.1f;
  String name = "";
};

enum WifiCredentialSaveResult : uint8_t {
  WIFI_CREDENTIAL_SAVED,
  WIFI_CREDENTIAL_UPDATED,
  WIFI_CREDENTIAL_FULL,
  WIFI_CREDENTIAL_ERROR
};

class Settings {

  private:
    String json_settings_string;

    // Flat cache populated once at begin() and kept in sync by saveSetting().
    // All loadSetting<T>() reads hit this struct — zero heap, zero JSON parse.
    struct SettingsCache {
      bool  ForcePMKID    = false;
      bool  ForceProbe    = false;
      bool  SavePCAP      = true;
      bool  EnableLED     = true;
      bool  EPDeauth      = false;
      bool  ChanHop       = false;
      String ClientSSID   = "";
      String ClientPW     = "";
      String wu           = "";
      String wt           = "";
      String wdg_key      = "";
    } _cache;

    void _buildCache();  // parse json_settings_string -> _cache

  public:
    bool begin();

    template <typename T>
    T loadSetting(const char* key);

    template <typename T>
    T saveSetting(const char* key, bool value);

    template <typename T>
    T saveSetting(const char* key, String value);

    bool toggleSetting(const char* key);
    const char* getSettingType(const char* key);
    String setting_index_to_name(int i);
    int getNumberSettings();

    String getSettingsString();
    uint8_t getSavedWifiCount();
    bool loadSavedWifiCredential(uint8_t index, String& ssid, String& password);
    WifiCredentialSaveResult saveWifiCredential(const String& ssid, const String& password, int8_t replace_index = -1);
    bool removeSavedWifiCredential(uint8_t index);
    bool markSavedWifiSuccessful(uint8_t index);
    bool loadGeofence(uint8_t index, GeofenceConfig& geofence);
    bool saveGeofence(uint8_t index, const GeofenceConfig& geofence);
    bool clearGeofence(uint8_t index);
    //bool createDefaultSettings(fs::FS &fs, bool spec = false, uint8_t index = 0, String typeStr = "bool", String name = "");
    bool createDefaultSettings(fs::FS &fs, bool spec = false, uint8_t index = 0, const char* typeStr = "bool", const char* name = "");
    void printJsonSettings(String json_string);
};

#endif

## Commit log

2026-09-25 chore: baseline PCB + review/plan docs
    - PCB source (EAGLE sch/brd), CAM, gerber zip, schematic PDF
    - docs/plans/pocketmarauder-firmware.md: hardware review + firmware plan (Opsi B OLED)
    - .gitignore for build artifacts and temp clones
    [espmarauder.brd, espmarauder.sch, espmarauder_production.brd]
2026-09-25 feat: vendor ESP32Marauder firmware + boot logo
    - firmware/ = upstream justcallmekoko/ESP32Marauder v1.17.0 (git metadata + submodule refs stripped, libs vendored flat)
    - pruned non-essential dirs (pictures, mechanical, PCBs, release bins, flashfiles)
    - firmware/esp32_marauder/pocket_logo.h: 128x64 1bpp Frenchie boot logo
    - tools/make_logo.py: regenerate logo from source image
    [t_dongle_c5.csv]
2026-09-25 feat: add POCKET_MARAUDER board target
    - configs.h: board flag, HARDWARE_NAME, feature block (BT/BUTTONS/SCREEN/MINI_SCREEN, no SD/GPS/battery)
    - button block L=IO32 C=IO33 U=IO35 D=IO25, all external pullups
    - display block SSD1306 128x64 I2C SDA=21 SCL=22 addr=0x3C, MENU_FONT NULL
    - CHANGELOG.md initialized
2026-09-25 chore: vendor AsyncTCP, ESP32Ping, EspSoftwareSerial, MicroNMEA libs
    Runtime deps the POCKET_MARAUDER firmware pulls in (async web server backend, ping utility, software serial, NMEA GPS parsing). Vendored under firmware/esp32_marauder/libraries/ so the PlatformIO build resolves them via lib_extra_dirs without network fetches.
2026-09-25 feat: add PlatformIO build env for POCKET_MARAUDER
    pioarduino platform fork (Arduino 3.3.12/IDF 5.5.5) additive [env:pocket_marauder]; pre-script fixes arduino-esp32 3.x bundled-lib include + Network link gaps; configs.h menu defs + OledAdapter GFX 3.x signature fixes. Build SUCCESS: Flash 80.9%, RAM 24.9%.
    [OledAdapter.h, configs.h]
2026-09-25 feat: enable battery ADC sensing + activity LED for POCKET_MARAUDER
2026-09-25 feat: add WPS scan, probe spam, GATT explore, roam-bait for POCKET_MARAUDER

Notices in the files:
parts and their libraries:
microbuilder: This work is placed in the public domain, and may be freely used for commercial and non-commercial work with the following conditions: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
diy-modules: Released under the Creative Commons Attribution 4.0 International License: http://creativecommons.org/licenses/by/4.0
